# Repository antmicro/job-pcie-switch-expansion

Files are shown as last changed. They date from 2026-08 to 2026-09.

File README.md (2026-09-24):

# PCIe Switch Expansion for Antmicro Baseboard for NVIDIA Jetson Orin

Copyright (c) 2026 [Antmicro](https://www.antmicro.com)
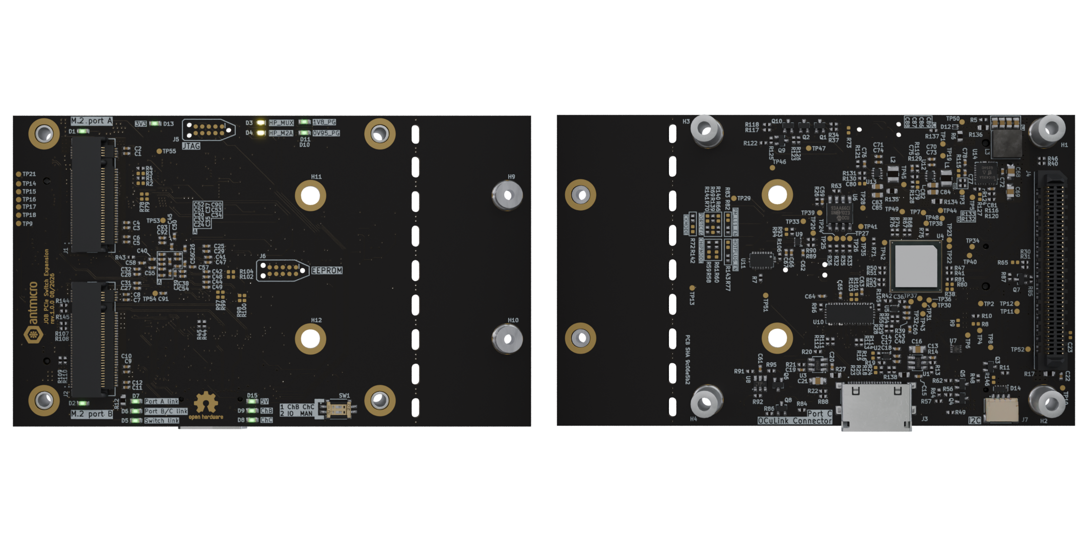
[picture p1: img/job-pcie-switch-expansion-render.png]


## Overview

This project contains open hardware PCB design files for an expansion board compatible with Antmicro's [Baseboard for Jetson Orin](https://github.com/antmicro/jetson-orin-baseboard).
The design includes a PCIe 3.0 switch that expands the number of available PCIe ports by connecting multiple PCIe endpoint devices to a single PCIe root complex.
The expansion board includes an OCuLink Connector and two M.2 (key-M) slots intended for connecting additional storage solutions with optional RAID support.
Both M.2 slots support 2280 and 2242 M.2 NVMe drives.
The design files were prepared in KiCad 10.x.

## Key features

* Accessory compatible with expansion connector located on Antmicro Baseboard NVIDIA Jetson Orin
* Supports for 2280 and 2242 M.2 NVMe drives
* 1x M.2 key M PCIe x2 slot 
* 1x M.2 key M or 1x OCuLink Connector PCIe x2 (multiplexed lane)
* 100 x 60 mm (3.94 x 2.36 inch) PCB outline

## Project structure 

The main directory contains KiCad PCB project files, the LICENSE, and this README, and the img directory contains graphics for this README.

## Licensing

This project is published under the [Apache-2.0](LICENSE) license.

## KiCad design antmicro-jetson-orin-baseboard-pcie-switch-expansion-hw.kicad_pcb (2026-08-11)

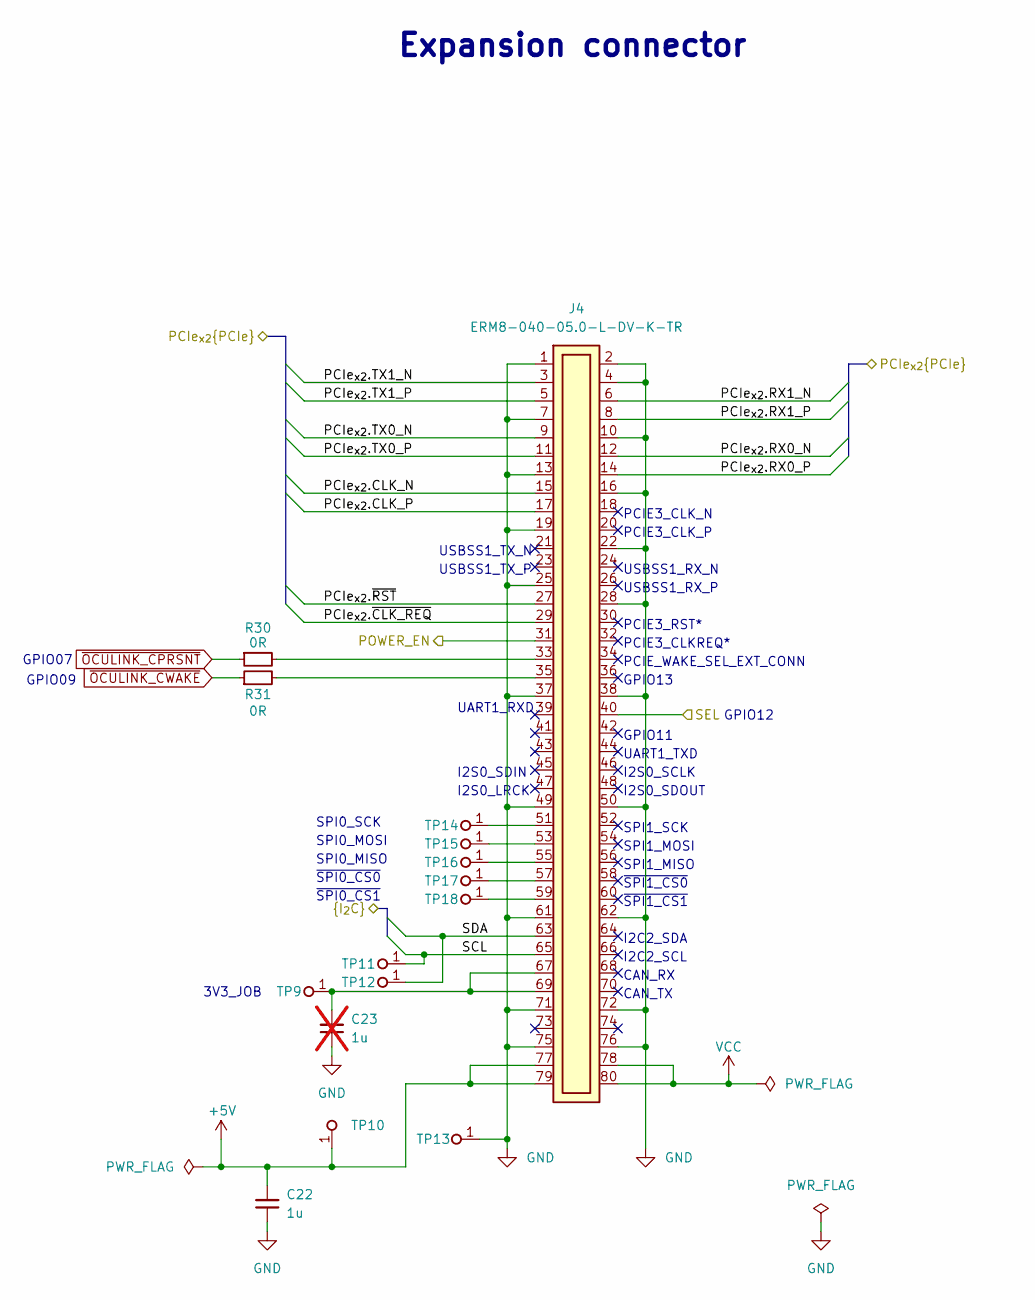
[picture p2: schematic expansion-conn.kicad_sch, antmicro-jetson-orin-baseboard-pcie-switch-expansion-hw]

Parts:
C22: C_1u_0402; C_0402_1005Metric; MPN C1005X6S1A105K050BC
C23: C_1u_0402; C_0402_1005Metric; MPN C1005X6S1A105K050BC; not fitted
J4: Plug_Samtec_ERM8_2x40_ERM8-040-05.0-L-DV-K-TR; Conn_Plug_Samtec_ERM8_2x40_ERM8-040-05.0-L-DV-K-TR; MPN ERM8-040-05.0-L-DV-K-TR
R30, R31: R_0R_0402; R_0402_1005Metric; MPN ERJ2GE0R00X
TP9, TP10, TP11, TP12, TP13, TP14, TP15, TP16, TP17, TP18: TP_0.75mm_SMD; TP_SMD_0.75mm

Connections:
+5V: C22.2, J4.77, J4.79, TP10.1 (1_1); also elsewhere on the board
/Expansion Connector/PCIe_{x2}.CLK_N: J4.15; also elsewhere on the board
/Expansion Connector/PCIe_{x2}.CLK_P: J4.17; also elsewhere on the board
/Expansion Connector/PCIe_{x2}.RX0_N: J4.12; also elsewhere on the board
/Expansion Connector/PCIe_{x2}.RX0_P: J4.14; also elsewhere on the board
/Expansion Connector/PCIe_{x2}.RX1_N: J4.6; also elsewhere on the board
/Expansion Connector/PCIe_{x2}.RX1_P: J4.8; also elsewhere on the board
/Expansion Connector/PCIe_{x2}.TX0_N: J4.9; also elsewhere on the board
/Expansion Connector/PCIe_{x2}.TX0_P: J4.11; also elsewhere on the board
/Expansion Connector/PCIe_{x2}.TX1_N: J4.3; also elsewhere on the board
/Expansion Connector/PCIe_{x2}.TX1_P: J4.5; also elsewhere on the board
/Expansion Connector/PCIe_{x2}.~CLK_REQ: J4.29; also elsewhere on the board
/Expansion Connector/PCIe_{x2}.~RST: J4.27; also elsewhere on the board
/Expansion Connector/POWER_EN: J4.31; also elsewhere on the board
/Expansion Connector/SCL: J4.65, TP11.1 (1_1); also elsewhere on the board
/Expansion Connector/SDA: J4.63, TP12.1 (1_1); also elsewhere on the board
/Expansion Connector/SEL: J4.40; also elsewhere on the board
GND: C22.1, C23.1, J4.1, J4.2, J4.4, J4.7, J4.10, J4.13, J4.16, J4.19, J4.22, J4.25, J4.28, J4.37, J4.38, J4.49, J4.50, J4.61, J4.62, J4.71, J4.72, J4.75, J4.76, TP13.1 (1_1); also elsewhere on the board
unnamed: C23.2, J4.67, J4.69, TP9.1 (1_1)
unnamed: J4.33, R30.2
unnamed: J4.35, R31.2
unnamed: J4.51, TP14.1 (1_1)
unnamed: J4.53, TP15.1 (1_1)
unnamed: J4.55, TP16.1 (1_1)
unnamed: J4.57, TP17.1 (1_1)
unnamed: J4.59, TP18.1 (1_1)
VCC: J4.78, J4.80; also elsewhere on the board
~OCULINK_CPRSNT: R30.1; also elsewhere on the board
~OCULINK_CWAKE: R31.1; also elsewhere on the board

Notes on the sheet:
USBSS1_RX_P
~{SPI1_CS1}
SPI0_MOSI
UART1_RXD
I2S0_SDOUT
PCIE3_CLK_N
~{SPI0_CS0}
I2S0_SDIN
USBSS1_RX_N
GPIO07
CAN_TX
PCIE3_CLK_P
SPI0_MISO
~{SPI0_CS1}
I2S0_LRCK
PCIE3_CLKREQ*
USBSS1_TX_P
I2C2_SCL
SPI1_MISO
SPI0_SCK
UART1_TXD
GPIO11
SPI1_MOSI
PCIE3_RST*
I2C2_SDA
~{SPI1_CS0}
GPIO13
CAN_RX
GPIO12
PCIE_WAKE_SEL_EXT_CONN
Expansion connector
USBSS1_TX_N
GPIO09
3V3_JOB
I2S0_SCLK
SPI1_SCK

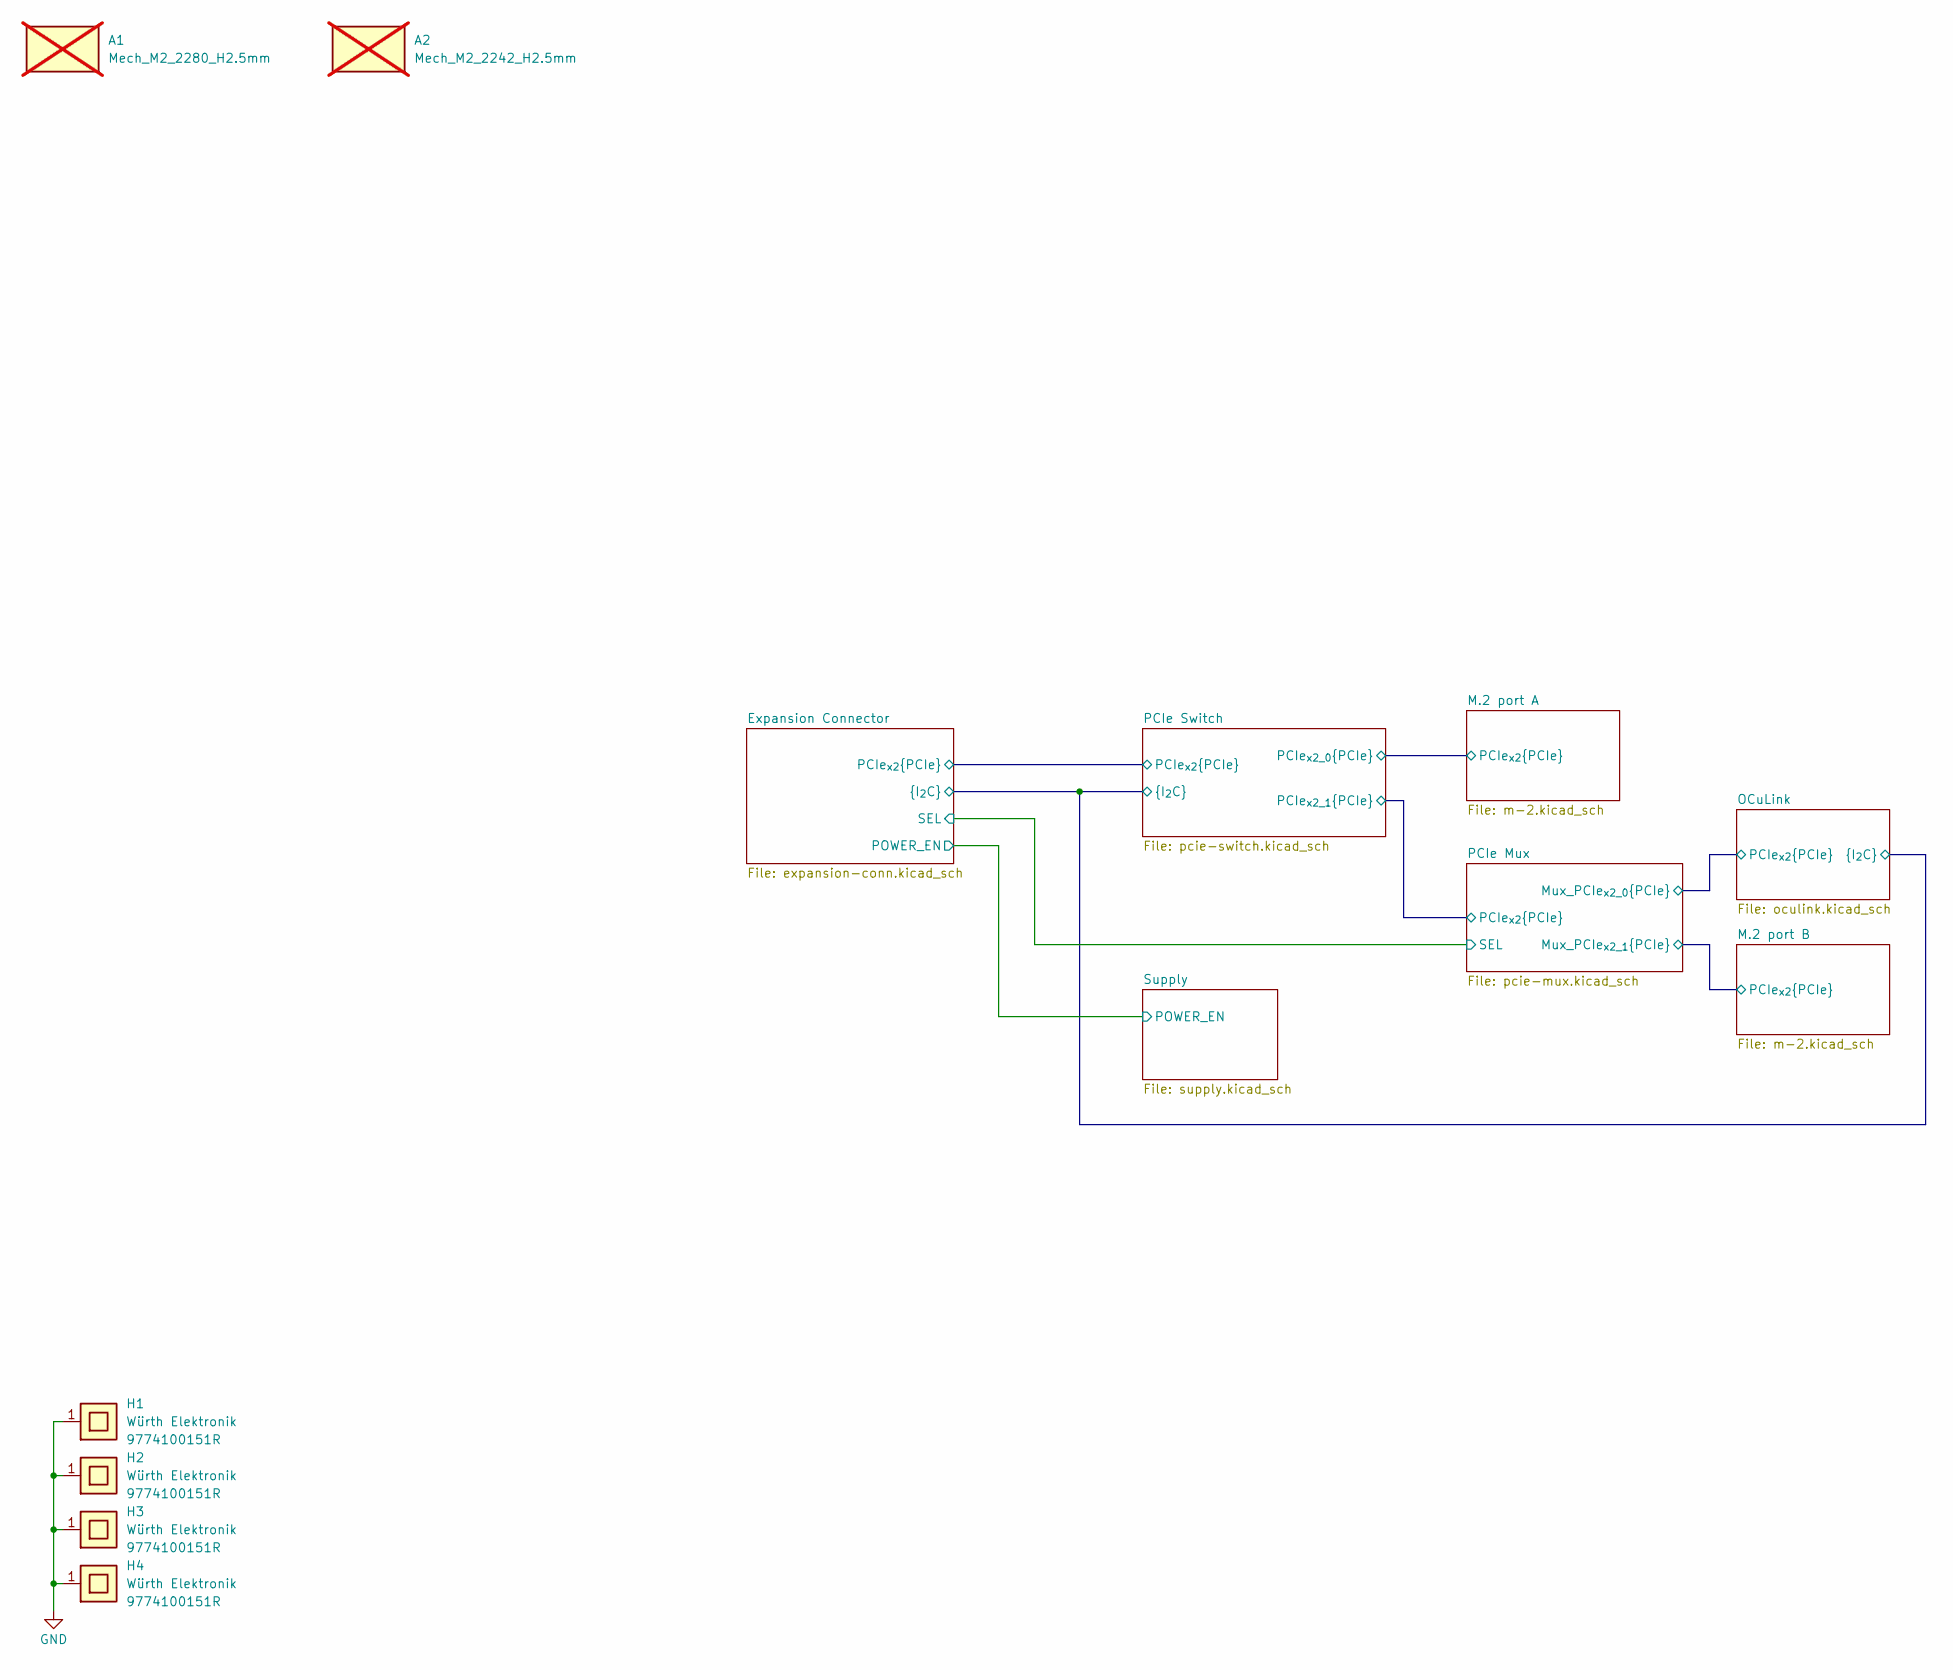
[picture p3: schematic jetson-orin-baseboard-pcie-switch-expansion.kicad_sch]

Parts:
A1: Mech_M2_2280_H2.5mm; not fitted
A2: Mech_M2_2242_H2.5mm; not fitted
H1, H2, H3, H4: Spacer_Drill3.7mm_H10mm_9774100151R; MPN 9774100151R

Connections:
GND: H1.1, H2.1, H3.1, H4.1; also elsewhere on the board

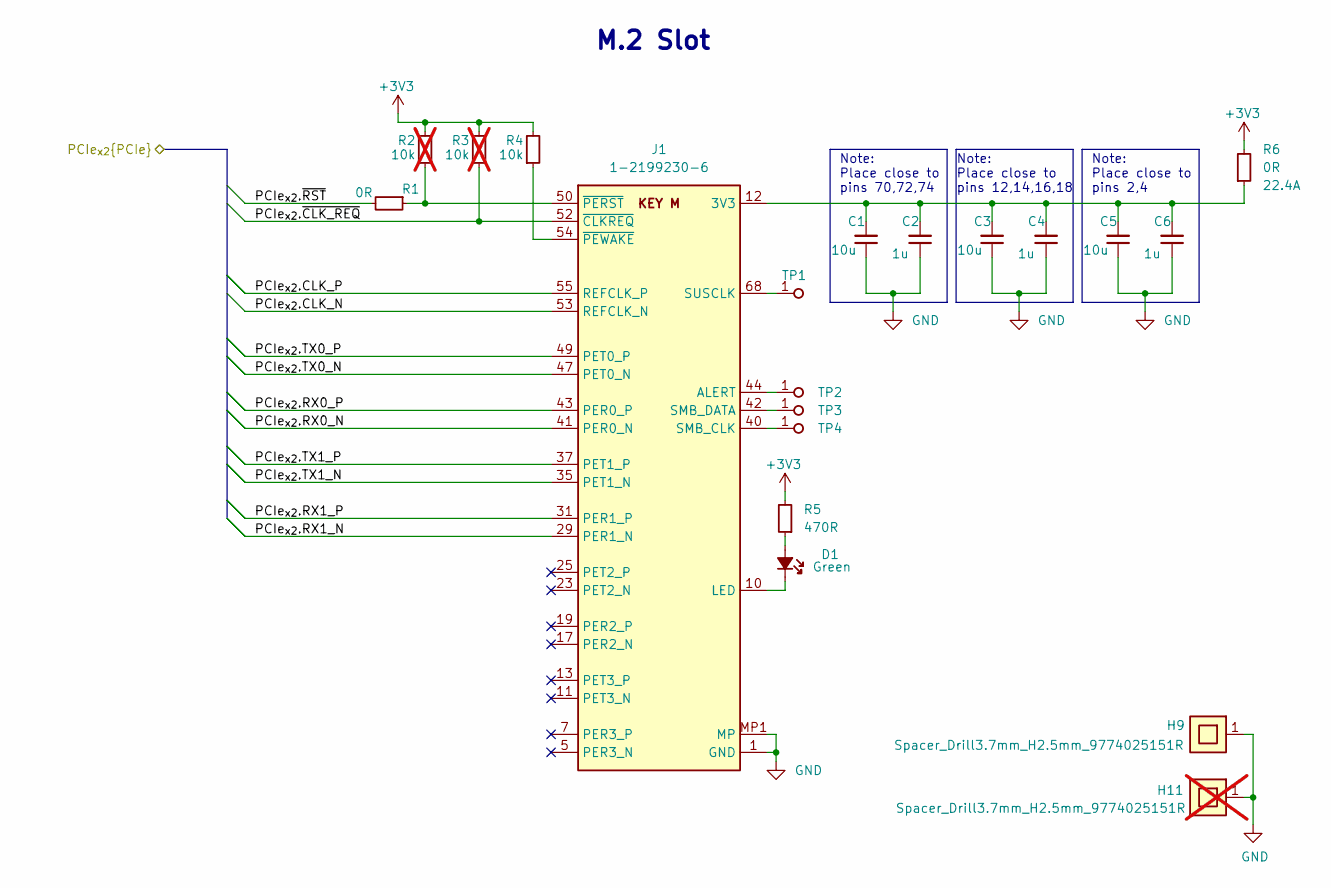
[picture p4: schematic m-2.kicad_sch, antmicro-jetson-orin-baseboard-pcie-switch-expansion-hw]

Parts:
C1, C3, C5: C_10u_0402; C_0402_1005Metric; MPN CC0402MRX5R5BB106
C2, C4, C6: C_1u_0402; C_0402_1005Metric; MPN C1005X6S1A105K050BC
D1: LED_G_0603_KP-1608CGCK; LED_0603_1608Metric_G; MPN KP-1608CGCK
H9: Spacer_Drill3.7mm_H2.5mm_9774025151R; MPN 9774025151R
H11: Spacer_Drill3.7mm_H2.5mm_9774025151R; MPN 9774025151R; not fitted
J1: Bus_M.2_1-2199230-6; Bus_M.2_Socket_Key_M_TE_1-2199230-6; MPN 1-2199230-6
R1: R_0R_0402; R_0402_1005Metric; MPN ERJ2GE0R00X
R2, R3: R_10k_0402; R_0402_1005Metric; Tolerance 1%; MPN CR0402-FX-1002GLF; not fitted
R4: R_10k_0402; R_0402_1005Metric; Tolerance 1%; MPN CR0402-FX-1002GLF
R5: R_470R_0402; R_0402_1005Metric; Tolerance 1%; MPN CR0402-FX-4700GLF
R6: R_0R_22.4A_0603; R_0603_1608Metric; Tolerance template_tolerance; MPN PMR03EZPJ000
TP1, TP2, TP3, TP4: TP_0.75mm_SMD; TP_SMD_0.75mm

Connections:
+3V3: R2.2, R3.2, R4.2, R5.2, R6.2; also elsewhere on the board
/M.2 port A/PCIe_{x2}.CLK_N: J1.53 (REFCLK_N); also elsewhere on the board
/M.2 port A/PCIe_{x2}.CLK_P: J1.55 (REFCLK_P); also elsewhere on the board
/M.2 port A/PCIe_{x2}.RX0_N: J1.41 (PER0_N); also elsewhere on the board
/M.2 port A/PCIe_{x2}.RX0_P: J1.43 (PER0_P); also elsewhere on the board
/M.2 port A/PCIe_{x2}.RX1_N: J1.29 (PER1_N); also elsewhere on the board
/M.2 port A/PCIe_{x2}.RX1_P: J1.31 (PER1_P); also elsewhere on the board
/M.2 port A/PCIe_{x2}.TX0_N: J1.47 (PET0_N); also elsewhere on the board
/M.2 port A/PCIe_{x2}.TX0_P: J1.49 (PET0_P); also elsewhere on the board
/M.2 port A/PCIe_{x2}.TX1_N: J1.35 (PET1_N); also elsewhere on the board
/M.2 port A/PCIe_{x2}.TX1_P: J1.37 (PET1_P); also elsewhere on the board
/M.2 port A/PCIe_{x2}.~CLK_REQ: J1.52 (~CLKREQ), R3.1; also elsewhere on the board
/M.2 port A/PCIe_{x2}.~RST: R1.2; also elsewhere on the board
GND: C1.1, C2.1, C3.1, C4.1, C5.1, C6.1, H9.1, H11.1, J1.1 (GND), J1.3 (GND), J1.9 (GND), J1.15 (GND), J1.21 (GND), J1.27 (GND), J1.33 (GND), J1.39 (GND), J1.45 (GND), J1.51 (GND), J1.57 (GND), J1.71 (GND), J1.73 (GND), J1.75 (GND), J1.MP1 (MP), J1.MP2 (MP); also elsewhere on the board
unnamed: C1.2, C2.2, C3.2, C4.2, C5.2, C6.2, J1.2 (3V3), J1.4 (3V3), J1.12 (3V3), J1.14 (3V3), J1.16 (3V3), J1.18 (3V3), J1.70 (3V3), J1.72 (3V3), J1.74 (3V3), R6.1
unnamed: D1.2 (A), R5.1
unnamed: D1.1 (C), J1.10 (LED)
unnamed: J1.44 (ALERT), TP2.1 (1_1)
unnamed: J1.40 (SMB_CLK), TP4.1 (1_1)
unnamed: J1.42 (SMB_DATA), TP3.1 (1_1)
unnamed: J1.68 (SUSCLK), TP1.1 (1_1)
unnamed: J1.50 (~PERST), R1.1, R2.1
unnamed: J1.54 (~PEWAKE), R4.1

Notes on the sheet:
Note: Place close to pins 2,4
M.2 Slot
Note: Place close to pins 12,14,16,18
Note: Place close to pins 70,72,74

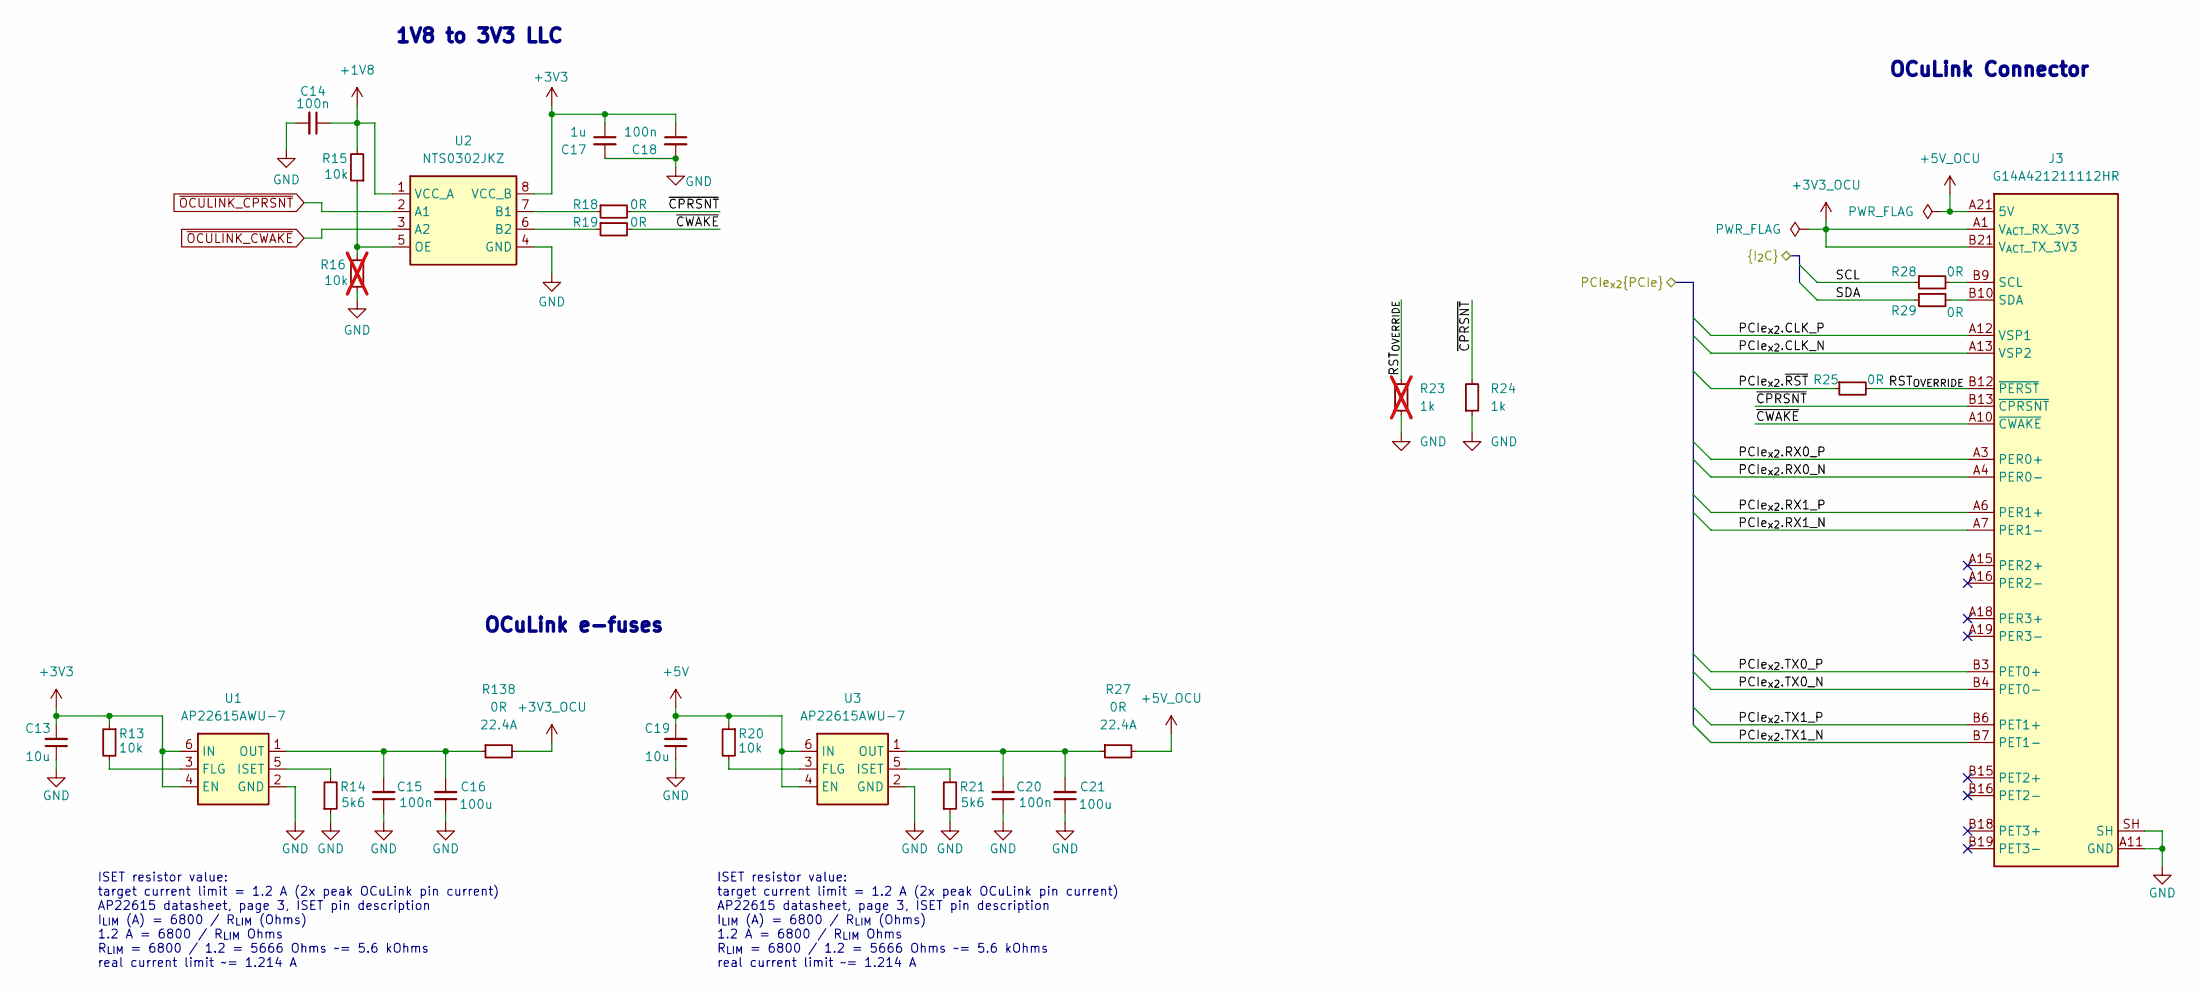
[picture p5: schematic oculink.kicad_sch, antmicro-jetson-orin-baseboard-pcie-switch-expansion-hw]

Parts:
C13, C19: C_10u_0402; C_0402_1005Metric; MPN CC0402MRX5R5BB106
C14, C15, C18, C20: C_100n_0402; C_0402_1005Metric; Voltage 50V; MPN GRM155R61H104KE14D
C16, C21: C_100u_0805; C_0805_2012Metric; MPN GRM21BR60J107ME15L
C17: C_1u_0402; C_0402_1005Metric; MPN C1005X6S1A105K050BC
J3: OCuLink_x4_Amphenol_G14A421211112HR; Amphenol_G14A421211112HR; MPN G14A421211112HR
R13, R15, R20: R_10k_0402; R_0402_1005Metric; Tolerance 1%; MPN CR0402-FX-1002GLF
R14, R21: R_5k6_0402; R_0402_1005Metric; Tolerance 1%; MPN CR0402-FX-5601GLF
R16: R_10k_0402; R_0402_1005Metric; Tolerance 1%; MPN CR0402-FX-1002GLF; not fitted
R18, R19, R25, R28, R29: R_0R_0402; R_0402_1005Metric; MPN ERJ2GE0R00X
R23: R_1k_0402; R_0402_1005Metric; Tolerance 1%; MPN CR0402-FX-1001GLF; not fitted
R24: R_1k_0402; R_0402_1005Metric; Tolerance 1%; MPN CR0402-FX-1001GLF
R27, R138: R_0R_22.4A_0603; R_0603_1608Metric; Tolerance template_tolerance; MPN PMR03EZPJ000
U1, U3: TSOT23-6; MPN AP22615AWU-7
U2: NTS0302JKZ; X2SON8_1.4x1x0.32mm_P0.35mm; MPN NTS0302JKZ

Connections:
+1V8: C14.1, R15.2, U2.1 (VCC_A); also elsewhere on the board
+3V3: C13.2, C17.1, C18.1, R13.1, U1.4 (EN), U1.6 (IN), U2.8 (VCC_B); also elsewhere on the board
+3V3_OCU: J3.A1 (V_{ACT}_RX_3V3), J3.B21 (V_{ACT}_TX_3V3), R138.2
+5V: C19.2, R20.1, U3.4 (EN), U3.6 (IN); also elsewhere on the board
+5V_OCU: J3.A21 (5V), J3.B1 (5V), R27.2
/Expansion Connector/SCL: R28.1; also elsewhere on the board
/Expansion Connector/SDA: R29.1; also elsewhere on the board
/OCuLink/PCIe_{x2}.CLK_N: J3.A13 (VSP2); also elsewhere on the board
/OCuLink/PCIe_{x2}.CLK_P: J3.A12 (VSP1); also elsewhere on the board
/OCuLink/PCIe_{x2}.RX0_N: J3.A4 (PER0-); also elsewhere on the board
/OCuLink/PCIe_{x2}.RX0_P: J3.A3 (PER0+); also elsewhere on the board
/OCuLink/PCIe_{x2}.RX1_N: J3.A7 (PER1-); also elsewhere on the board
/OCuLink/PCIe_{x2}.RX1_P: J3.A6 (PER1+); also elsewhere on the board
/OCuLink/PCIe_{x2}.TX0_N: J3.B4 (PET0-); also elsewhere on the board
/OCuLink/PCIe_{x2}.TX0_P: J3.B3 (PET0+); also elsewhere on the board
/OCuLink/PCIe_{x2}.TX1_N: J3.B7 (PET1-); also elsewhere on the board
/OCuLink/PCIe_{x2}.TX1_P: J3.B6 (PET1+); also elsewhere on the board
/OCuLink/PCIe_{x2}.~RST: R25.1; also elsewhere on the board
/OCuLink/RST_{OVERRIDE}: J3.B12 (~PERST), R23.2, R25.2
/OCuLink/~CPRSNT: J3.B13 (~CPRSNT), R18.2, R24.2
/OCuLink/~CWAKE: J3.A10 (~CWAKE), R19.2
GND: C13.1, C14.2, C15.1, C16.1, C17.2, C18.2, C19.1, C20.1, C21.1, J3.A2 (GND), J3.A5 (GND), J3.A8 (GND), J3.A11 (GND), J3.A14 (GND), J3.A17 (GND), J3.A20 (GND), J3.B2 (GND), J3.B5 (GND), J3.B8 (GND), J3.B11 (GND), J3.B14 (GND), J3.B17 (GND), J3.B20 (GND), J3.SH, R14.1, R16.1, R21.1, R23.1, R24.1, U1.2 (GND), U2.4 (GND), U3.2 (GND); also elsewhere on the board
unnamed: J3.B9 (SCL), R28.2
unnamed: J3.B10 (SDA), R29.2
unnamed: R13.2, U1.3 (FLG)
unnamed: R14.2, U1.5 (ISET)
unnamed: C15.2, C16.2, R138.1, U1.1 (OUT)
unnamed: R18.1, U2.7 (B1)
unnamed: R19.1, U2.6 (B2)
unnamed: R15.1, R16.2, U2.5 (OE)
unnamed: R20.2, U3.3 (FLG)
unnamed: R21.2, U3.5 (ISET)
unnamed: C20.2, C21.2, R27.1, U3.1 (OUT)
~OCULINK_CPRSNT: U2.2 (A1); also elsewhere on the board
~OCULINK_CWAKE: U2.3 (A2); also elsewhere on the board

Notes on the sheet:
ISET resistor value: target current limit = 1.2 A (2x peak OCuLink pin current) AP22615 datasheet, page 3, ISET pin description I_{LIM} (A) = 6800 / R_{LIM} (Ohms) 1.2 A = 6800 / R_{LIM} Ohms R_{LIM} = 6800 / 1.2 = 5666 Ohms ~= 5.6 kOhms real current limit ~= 1.214 A
OCuLink e-fuses
1V8 to 3V3 LLC
OCuLink Connector

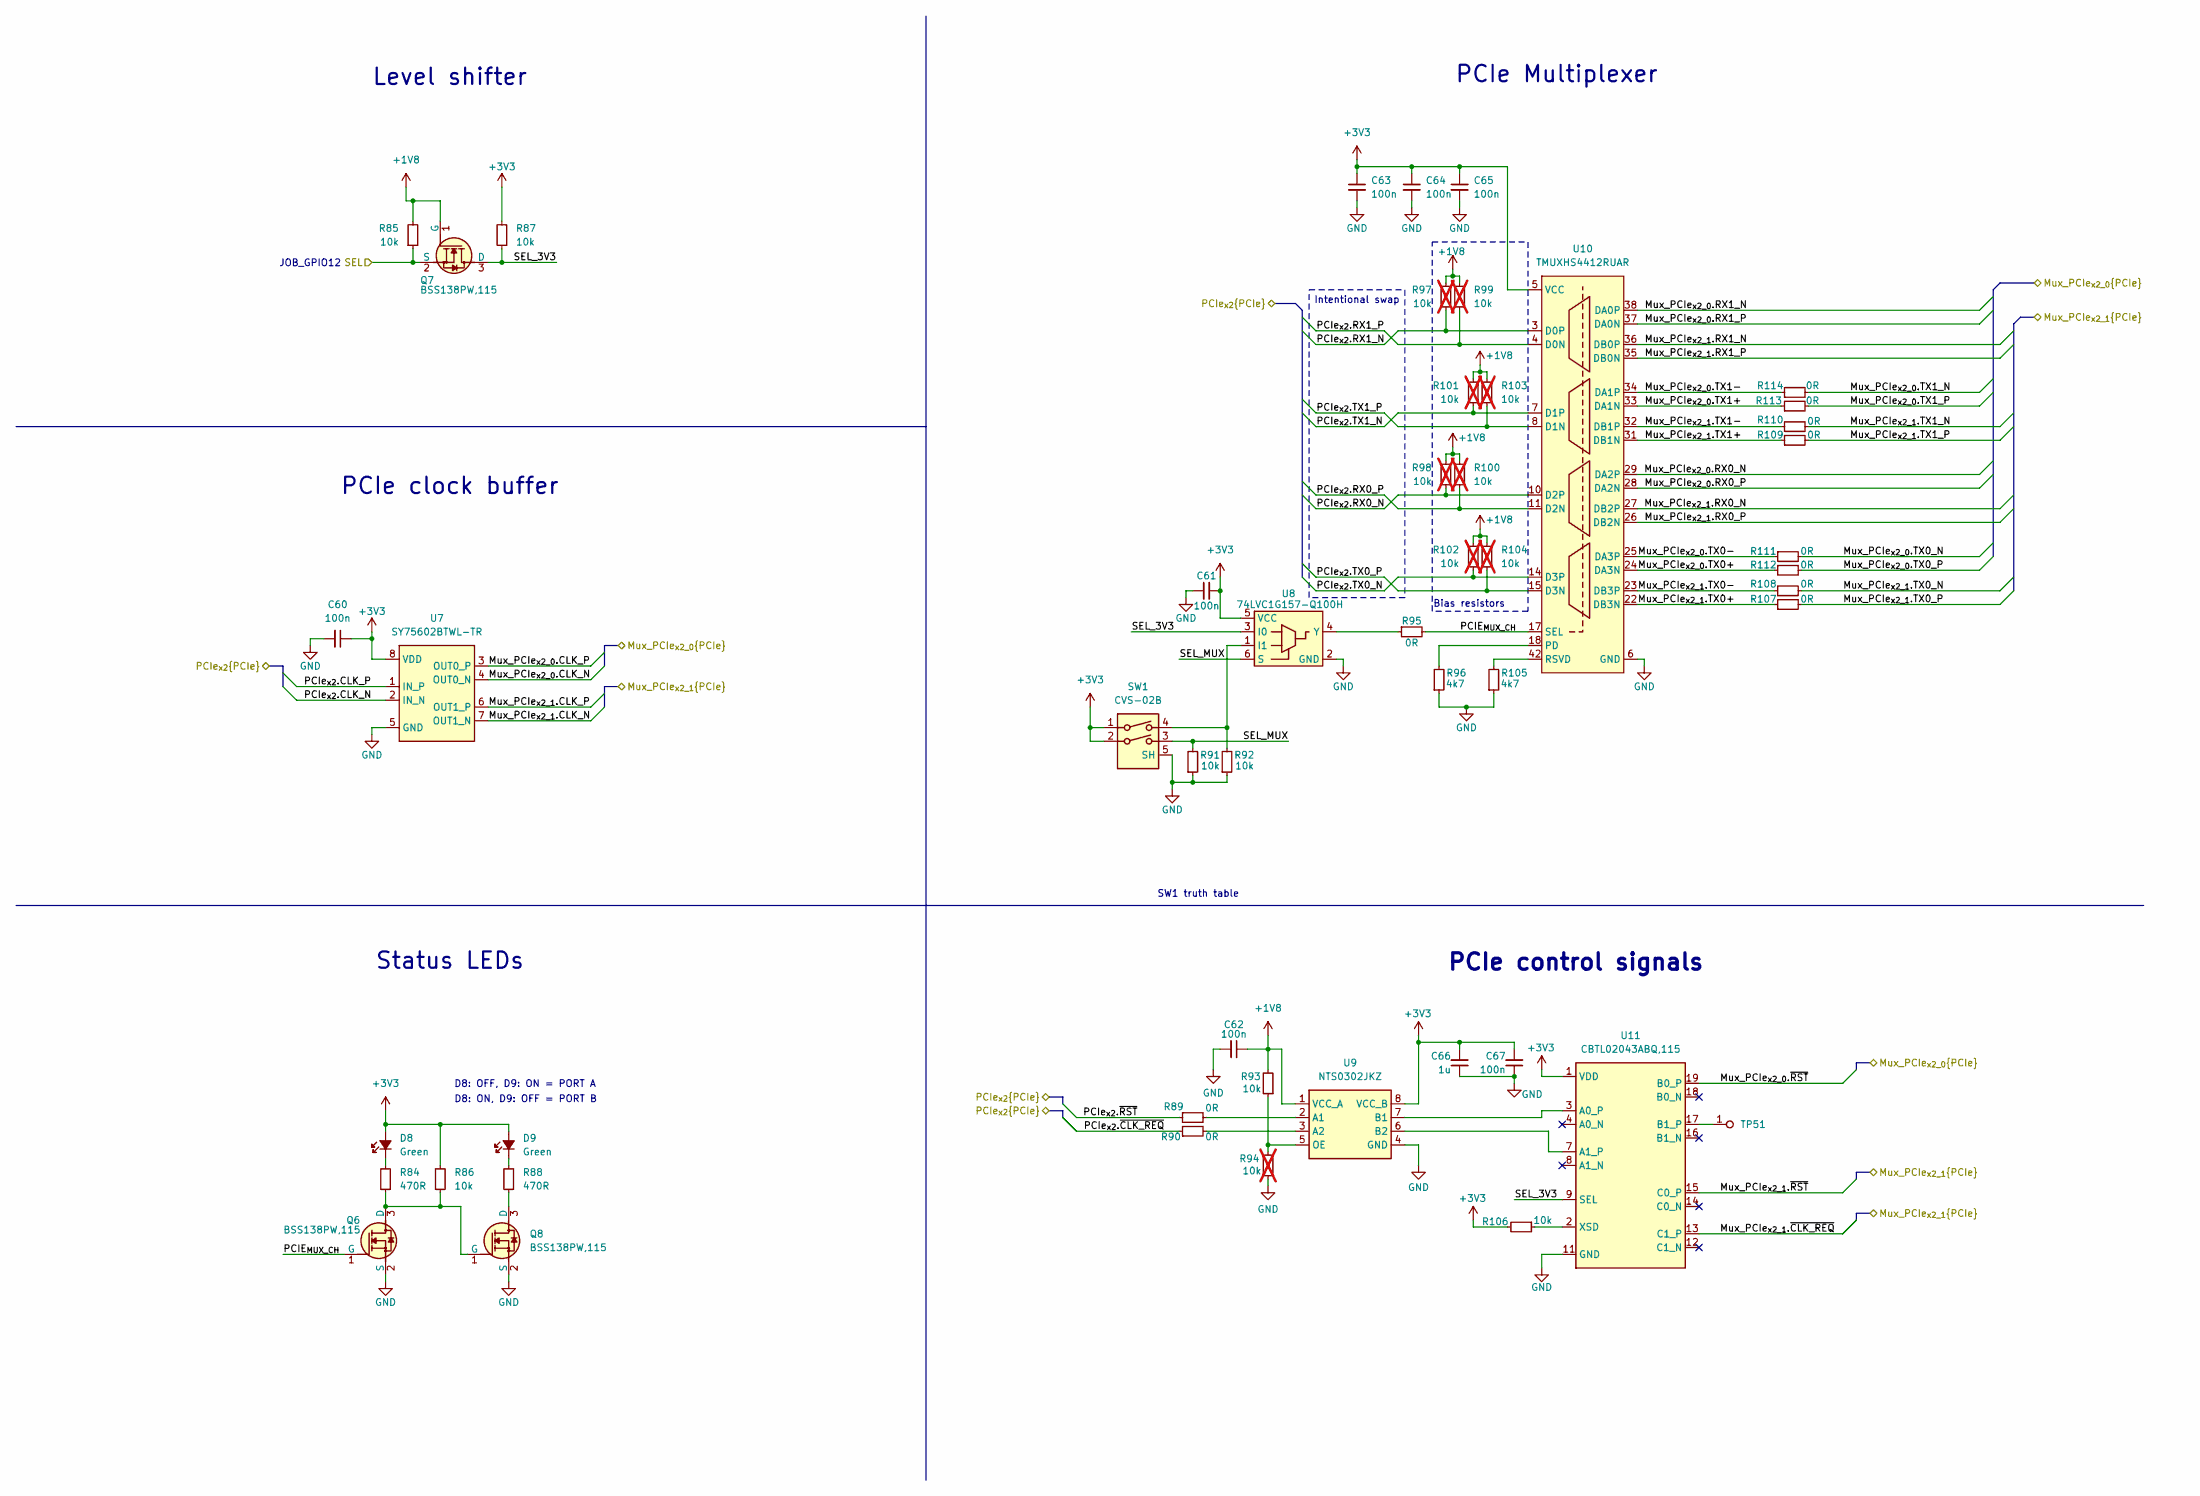
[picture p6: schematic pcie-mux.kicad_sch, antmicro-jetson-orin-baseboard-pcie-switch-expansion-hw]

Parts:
C60, C61, C62, C63, C64, C65, C67: C_100n_0402; C_0402_1005Metric; Voltage 50V; MPN GRM155R61H104KE14D
C66: C_1u_0402; C_0402_1005Metric; MPN C1005X6S1A105K050BC
D8, D9: LED_G_0603_LG_L29K-G2J1-24-Z; LED_0603_1608Metric_G; MPN LG L29K-G2J1-24-Z
Q6, Q7, Q8: BSS138PW,115; SC70-3; MPN BSS138PW,115
R84, R88: R_470R_0402; R_0402_1005Metric; Tolerance 1%; MPN CR0402-FX-4700GLF
R85, R86, R87, R91, R92, R93, R106: R_10k_0402; R_0402_1005Metric; Tolerance 1%; MPN CR0402-FX-1002GLF
R89, R90, R95, R107, R108, R109, R110, R111, R112, R113, R114: R_0R_0402; R_0402_1005Metric; MPN ERJ2GE0R00X
R94, R97, R98, R99, R100, R101, R102, R103, R104: R_10k_0402; R_0402_1005Metric; Tolerance 1%; MPN CR0402-FX-1002GLF; not fitted
R96, R105: R_4k7_0402; R_0402_1005Metric; Tolerance 1%; MPN CR0402-FX-4701GLF
SW1: SW_CVS-02B; SW_DIP_SPSTx02_Slide_Copal_CVS-02xB_W5.9mm_P1mm; MPN CVS-02B
TP51: TP_1mm_SMD; TP_SMD_1mm
U7: SY75602BTWL-TR; VDFN-8_1.6x1.4mm_P0.4mm; MPN SY75602BTWL-TR
U8: 74LVC1G157-Q100H_SOT457; SC-74-6_1.5x2.9mm_P0.95mm; MPN 74LVC1G157-Q100H
U9: NTS0302JKZ; X2SON8_1.4x1x0.32mm_P0.35mm; MPN NTS0302JKZ
U10: TMUXHS4412RUAR; WQFN-42-1EP_3.5x9mm_P0.5mm; MPN TMUXHS4412RUAR
U11: CBTL02043ABQ; DHVQFN-20-1EP_2.5x4.5_P0.5mm; MPN CBTL02043ABQ,115

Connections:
+1V8: C62.1, Q7.1 (G), R85.2, R93.2, R97.2, R98.2, R99.2, R100.2, R101.2, R102.2, R103.2, R104.2, U9.1 (VCC_A); also elsewhere on the board
+3V3: C60.1, C61.2, C63.1, C64.1, C65.1, C66.2, C67.2, D8.2 (A), D9.2 (A), R86.2, R87.2, R106.2, SW1.1, SW1.2, U7.8 (VDD), U8.5 (VCC), U9.8 (VCC_B), U10.5 (VCC), U10.13 (VCC), U11.1 (VDD), U11.6 (VDD), U11.10 (VDD); also elsewhere on the board
/Expansion Connector/SEL: Q7.2 (S), R85.1; also elsewhere on the board
/M.2 port B/PCIe_{x2}.CLK_N: U7.7 (OUT1_N); also elsewhere on the board
/M.2 port B/PCIe_{x2}.CLK_P: U7.6 (OUT1_P); also elsewhere on the board
/M.2 port B/PCIe_{x2}.RX0_N: U10.27 (DB2P); also elsewhere on the board
/M.2 port B/PCIe_{x2}.RX0_P: U10.26 (DB2N); also elsewhere on the board
/M.2 port B/PCIe_{x2}.RX1_N: U10.36 (DB0P); also elsewhere on the board
/M.2 port B/PCIe_{x2}.RX1_P: U10.35 (DB0N); also elsewhere on the board
/M.2 port B/PCIe_{x2}.TX0_N: R108.2; also elsewhere on the board
/M.2 port B/PCIe_{x2}.TX0_P: R107.2; also elsewhere on the board
/M.2 port B/PCIe_{x2}.TX1_N: R110.2; also elsewhere on the board
/M.2 port B/PCIe_{x2}.TX1_P: R109.2; also elsewhere on the board
/M.2 port B/PCIe_{x2}.~CLK_REQ: U11.13 (C1_P); also elsewhere on the board
/M.2 port B/PCIe_{x2}.~RST: U11.15 (C0_P); also elsewhere on the board
/OCuLink/PCIe_{x2}.CLK_N: U7.4 (OUT0_N); also elsewhere on the board
/OCuLink/PCIe_{x2}.CLK_P: U7.3 (OUT0_P); also elsewhere on the board
/OCuLink/PCIe_{x2}.RX0_N: U10.29 (DA2P); also elsewhere on the board
/OCuLink/PCIe_{x2}.RX0_P: U10.28 (DA2N); also elsewhere on the board
/OCuLink/PCIe_{x2}.RX1_N: U10.38 (DA0P); also elsewhere on the board
/OCuLink/PCIe_{x2}.RX1_P: U10.37 (DA0N); also elsewhere on the board
/OCuLink/PCIe_{x2}.TX0_N: R111.2; also elsewhere on the board
/OCuLink/PCIe_{x2}.TX0_P: R112.2; also elsewhere on the board
/OCuLink/PCIe_{x2}.TX1_N: R114.2; also elsewhere on the board
/OCuLink/PCIe_{x2}.TX1_P: R113.2; also elsewhere on the board
/OCuLink/PCIe_{x2}.~RST: U11.19 (B0_P); also elsewhere on the board
/PCIe Mux/Mux_PCIe_{x2_0}.TX0+: R112.1, U10.24 (DA3N)
/PCIe Mux/Mux_PCIe_{x2_0}.TX0-: R111.1, U10.25 (DA3P)
/PCIe Mux/Mux_PCIe_{x2_0}.TX1+: R113.1, U10.33 (DA1N)
/PCIe Mux/Mux_PCIe_{x2_0}.TX1-: R114.1, U10.34 (DA1P)
/PCIe Mux/Mux_PCIe_{x2_1}.TX0+: R107.1, U10.22 (DB3N)
/PCIe Mux/Mux_PCIe_{x2_1}.TX0-: R108.1, U10.23 (DB3P)
/PCIe Mux/Mux_PCIe_{x2_1}.TX1+: R109.1, U10.31 (DB1N)
/PCIe Mux/Mux_PCIe_{x2_1}.TX1-: R110.1, U10.32 (DB1P)
/PCIe Mux/PCIE_{MUX_CH}: Q6.1 (G), R95.2, U10.17 (SEL)
/PCIe Mux/PCIe_{x2}.CLK_N: U7.2 (IN_N); also elsewhere on the board
/PCIe Mux/PCIe_{x2}.CLK_P: U7.1 (IN_P); also elsewhere on the board
/PCIe Mux/PCIe_{x2}.RX0_N: R98.1, U10.10 (D2P); also elsewhere on the board
/PCIe Mux/PCIe_{x2}.RX0_P: R100.1, U10.11 (D2N); also elsewhere on the board
/PCIe Mux/PCIe_{x2}.RX1_N: R97.1, U10.3 (D0P); also elsewhere on the board
/PCIe Mux/PCIe_{x2}.RX1_P: R99.1, U10.4 (D0N); also elsewhere on the board
/PCIe Mux/PCIe_{x2}.TX0_N: R102.1, U10.14 (D3P); also elsewhere on the board
/PCIe Mux/PCIe_{x2}.TX0_P: R104.1, U10.15 (D3N); also elsewhere on the board
/PCIe Mux/PCIe_{x2}.TX1_N: R101.1, U10.7 (D1P); also elsewhere on the board
/PCIe Mux/PCIe_{x2}.TX1_P: R103.1, U10.8 (D1N); also elsewhere on the board
/PCIe Mux/PCIe_{x2}.~CLK_REQ: R90.1; also elsewhere on the board
/PCIe Mux/PCIe_{x2}.~RST: R89.1; also elsewhere on the board
/PCIe Mux/SEL_3V3: Q7.3 (D), R87.1, U8.3 (I0), U11.9 (SEL)
/PCIe Mux/SEL_MUX: R91.2, SW1.3, U8.6 (S)
GND: C60.2, C61.1, C62.2, C63.2, C64.2, C65.2, C66.1, C67.1, Q6.2 (S), Q8.2 (S), R91.1, R92.1, R94.1, R96.1, R105.1, SW1.5 (SH_5), U7.5 (GND), U8.2 (GND), U9.4 (GND), U10.6 (GND), U10.9 (GND), U10.16 (GND), U10.21 (GND), U10.30 (GND), U10.39 (GND), U10.43 (GND), U11.5 (GND), U11.11 (GND), U11.20 (GND), U11.21 (GND); also elsewhere on the board
unnamed: D8.1 (C), R84.2
unnamed: D9.1 (C), R88.2
unnamed: Q6.3 (D), Q8.1 (G), R84.1, R86.1
unnamed: Q8.3 (D), R88.1
unnamed: R92.2, SW1.4, U8.1 (I1)
unnamed: R95.1, U8.4 (Y)
unnamed: R89.2, U9.2 (A1)
unnamed: R90.2, U9.3 (A2)
unnamed: R93.1, R94.2, U9.5 (OE)
unnamed: R96.2, U10.18 (PD)
unnamed: R105.2, U10.42 (RSVD)
unnamed: U9.7 (B1), U11.3 (A0_P)
unnamed: U9.6 (B2), U11.7 (A1_P)
unnamed: TP51.1 (1_1), U11.17 (B1_P)
unnamed: R106.1, U11.2 (XSD)

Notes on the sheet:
JOB_GPIO12
Level shifter
PCIe clock buffer
SW1 truth table
PCIe Multiplexer
Bias resistors
Intentional swap
D8: OFF, D9: ON = PORT A
Status LEDs
D8: ON, D9: OFF = PORT B
PCIe control signals

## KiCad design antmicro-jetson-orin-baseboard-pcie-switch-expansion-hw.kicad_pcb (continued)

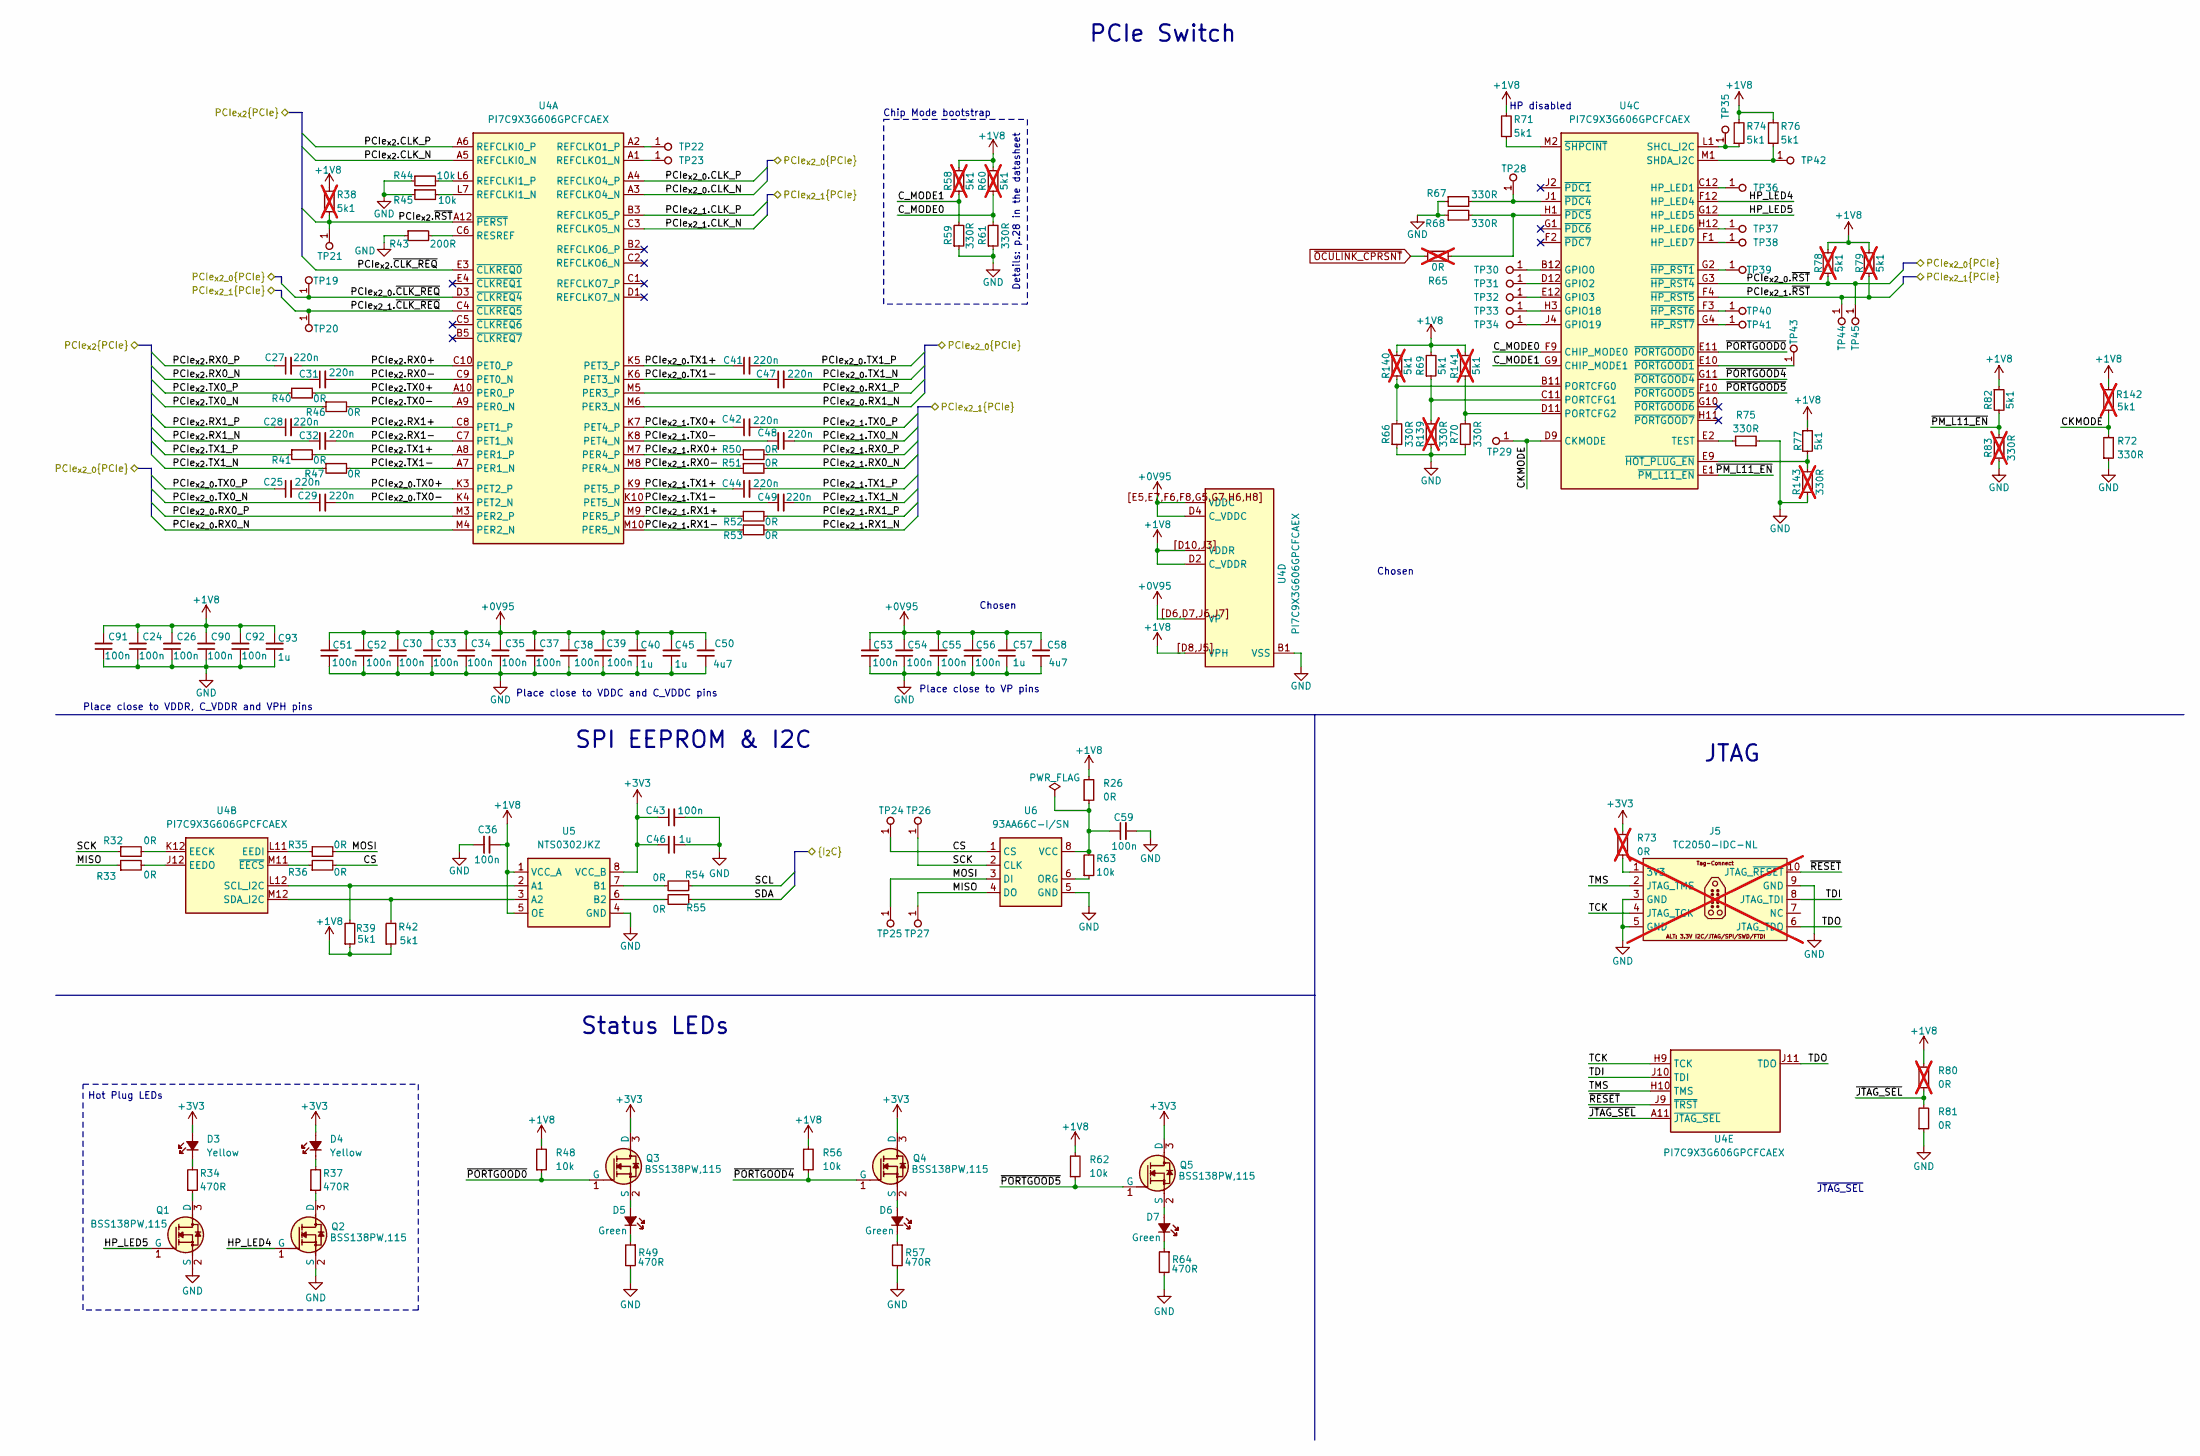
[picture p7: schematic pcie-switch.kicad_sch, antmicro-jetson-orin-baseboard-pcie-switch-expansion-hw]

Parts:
C24, C26, C30, C33, C34, C35, C36, C37, C38, C39, C43, C51, C52, C53, C54, C55, C56, C59, C90, C91, C92: C_100n_0402; C_0402_1005Metric; Voltage 50V; MPN GRM155R61H104KE14D
C25, C27, C28, C29, C31, C32, C41, C42, C44, C47, C48, C49: C_220n_0402; C_0402_1005Metric; MPN CC0402KRX5R6BB224
C40, C45, C46, C57, C93: C_1u_0402; C_0402_1005Metric; MPN C1005X6S1A105K050BC
C50, C58: C_4u7_25V_0402; C_0402_1005Metric; Voltage 25V; MPN GRM155C61E475ME15J
D3, D4: LED_Y_0402_VLMY1500-GS08; LED_0402_1005Metric_Y; MPN VLMY1500-GS08
D5, D6, D7: LED_G_0603_LG_L29K-G2J1-24-Z; LED_0603_1608Metric_G; MPN LG L29K-G2J1-24-Z
J5: Tag-Connect_TC2050-IDC-NL_2x5_P1.27mm; MPN TC2050-IDC-NL; not fitted
Q1, Q2, Q3, Q4, Q5: BSS138PW,115; SC70-3; MPN BSS138PW,115
R26, R32, R33, R35, R36, R40, R41, R46, R47, R50, R51, R52, R53, R54, R55, R81: R_0R_0402; R_0402_1005Metric; MPN ERJ2GE0R00X
R34, R37, R49, R57, R64: R_470R_0402; R_0402_1005Metric; Tolerance 1%; MPN CR0402-FX-4700GLF
R38, R58, R60, R78, R79, R140, R141, R142: R_5k1_0402; R_0402_1005Metric; Tolerance 1%; MPN CR0402-FX-5101GLF; not fitted
R39, R42, R69, R71, R74, R76, R77, R82: R_5k1_0402; R_0402_1005Metric; Tolerance 1%; MPN CR0402-FX-5101GLF
R43: R_200R_0402; R_0402_1005Metric; Tolerance 1%; MPN CR0402-FX-2000GLF
R44, R45, R48, R56, R62, R63: R_10k_0402; R_0402_1005Metric; Tolerance 1%; MPN CR0402-FX-1002GLF
R59, R61, R66, R67, R68, R70, R72, R75: R_330R_0402; R_0402_1005Metric; Tolerance 1%; MPN CR0402-FX-3300GLF
R65, R73, R80: R_0R_0402; R_0402_1005Metric; MPN ERJ2GE0R00X; not fitted
R83, R139, R143: R_330R_0402; R_0402_1005Metric; Tolerance 1%; MPN CR0402-FX-3300GLF; not fitted
TP19, TP20, TP21, TP22, TP23, TP28, TP29, TP30, TP31, TP32, TP33, TP34, TP35, TP36, TP37, TP38, TP39, TP40, TP41, TP42, TP43, TP44, TP45: TP_1mm_SMD; TP_SMD_1mm
TP24, TP25, TP26, TP27: TP_0.75mm_SMD; TP_SMD_0.75mm
U4: PI7C9X3G606GP; BGA-144_10x10mm_Layout12x12_P0.8mm; MPN PI7C9X3G606GPCFCAEX
U5: NTS0302JKZ; X2SON8_1.4x1x0.32mm_P0.35mm; MPN NTS0302JKZ
U6: 93AA66C_SOIC; SOIC-8_3.9x4.9x1.75mm_P1.27mm; MPN 93AA66C-I/SN

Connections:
+0V95: C30.2, C33.2, C34.2, C35.2, C37.2, C38.2, C39.2, C40.2, C45.2, C50.2, C51.2, C52.2, C53.2, C54.2, C55.2, C56.2, C57.2, C58.2, U4.D4 (C_VDDC), U4.D6 (VP), U4.D7 (VP), U4.E5 (VDDC), U4.E7 (VDDC), U4.F6 (VDDC), U4.F8 (VDDC), U4.G5 (VDDC), U4.G7 (VDDC), U4.H6 (VDDC), U4.H8 (VDDC), U4.J6 (VP), U4.J7 (VP), U4.[D6,D7,J6,J7] (VP), U4.[E5,E7,F6,F8,G5,G7,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 (VDDC); also elsewhere on the board
+1V8: C24.2, C26.2, C36.1, C90.2, C91.2, C92.2, C93.2, R26.2, R38.2, R39.1, R42.1, R48.2, R56.2, R58.2, R60.2, R62.2, R69.2, R71.2, R74.2, R76.2, R77.1, R78.1, R79.1, R80.2, R82.1, R140.2, R141.2, R142.1, U4.D2 (C_VDDR), U4.D8 (VPH), U4.D10 (VDDR), U4.J3 (VDDR), U4.J5 (VPH), U4.[D8,J5] (VPH), U4.[D10,J3] (VDDR), U5.1 (VCC_A), U5.5 (OE); also elsewhere on the board
+3V3: C43.1, C46.2, D3.2 (A), D4.2 (A), Q3.3 (D), Q4.3 (D), Q5.3 (D), R73.2, U5.8 (VCC_B); also elsewhere on the board
/Expansion Connector/PCIe_{x2}.CLK_N: U4.A5 (REFCLKI0_N); also elsewhere on the board
/Expansion Connector/PCIe_{x2}.CLK_P: U4.A6 (REFCLKI0_P); also elsewhere on the board
/Expansion Connector/PCIe_{x2}.RX0_N: C31.1; also elsewhere on the board
/Expansion Connector/PCIe_{x2}.RX0_P: C27.1; also elsewhere on the board
/Expansion Connector/PCIe_{x2}.RX1_N: C32.1; also elsewhere on the board
/Expansion Connector/PCIe_{x2}.RX1_P: C28.1; also elsewhere on the board
/Expansion Connector/PCIe_{x2}.TX0_N: R46.1; also elsewhere on the board
/Expansion Connector/PCIe_{x2}.TX0_P: R40.1; also elsewhere on the board
/Expansion Connector/PCIe_{x2}.TX1_N: R47.1; also elsewhere on the board
/Expansion Connector/PCIe_{x2}.TX1_P: R41.1; also elsewhere on the board
/Expansion Connector/PCIe_{x2}.~CLK_REQ: U4.E3 (~CLKREQ0); also elsewhere on the board
/Expansion Connector/PCIe_{x2}.~RST: R38.1, TP21.1 (1_1), U4.A12 (~PERST); also elsewhere on the board
/Expansion Connector/SCL: R54.1; also elsewhere on the board
/Expansion Connector/SDA: R55.1; also elsewhere on the board
/M.2 port A/PCIe_{x2}.CLK_N: U4.A3 (REFCLKO4_N); also elsewhere on the board
/M.2 port A/PCIe_{x2}.CLK_P: U4.A4 (REFCLKO4_P); also elsewhere on the board
/M.2 port A/PCIe_{x2}.RX0_N: U4.M4 (PER2_N); also elsewhere on the board
/M.2 port A/PCIe_{x2}.RX0_P: U4.M3 (PER2_P); also elsewhere on the board
/M.2 port A/PCIe_{x2}.RX1_N: U4.M6 (PER3_N); also elsewhere on the board
/M.2 port A/PCIe_{x2}.RX1_P: U4.M5 (PER3_P); also elsewhere on the board
/M.2 port A/PCIe_{x2}.TX0_N: C29.1; also elsewhere on the board
/M.2 port A/PCIe_{x2}.TX0_P: C25.1; also elsewhere on the board
/M.2 port A/PCIe_{x2}.TX1_N: C47.2; also elsewhere on the board
/M.2 port A/PCIe_{x2}.TX1_P: C41.2; also elsewhere on the board
/M.2 port A/PCIe_{x2}.~CLK_REQ: TP19.1 (1_1), U4.D3 (~CLKREQ4); also elsewhere on the board
/M.2 port A/PCIe_{x2}.~RST: R78.2, TP45.1 (1_1), U4.G3 (~HP_RST4); also elsewhere on the board
/PCIe Mux/PCIe_{x2}.CLK_N: U4.C3 (REFCLKO5_N); also elsewhere on the board
/PCIe Mux/PCIe_{x2}.CLK_P: U4.B3 (REFCLKO5_P); also elsewhere on the board
/PCIe Mux/PCIe_{x2}.RX0_N: R51.2; also elsewhere on the board
/PCIe Mux/PCIe_{x2}.RX0_P: R50.2; also elsewhere on the board
/PCIe Mux/PCIe_{x2}.RX1_N: R53.2; also elsewhere on the board
/PCIe Mux/PCIe_{x2}.RX1_P: R52.2; also elsewhere on the board
/PCIe Mux/PCIe_{x2}.TX0_N: C48.2; also elsewhere on the board
/PCIe Mux/PCIe_{x2}.TX0_P: C42.2; also elsewhere on the board
/PCIe Mux/PCIe_{x2}.TX1_N: C49.2; also elsewhere on the board
/PCIe Mux/PCIe_{x2}.TX1_P: C44.2; also elsewhere on the board
/PCIe Mux/PCIe_{x2}.~CLK_REQ: TP20.1 (1_1), U4.C4 (~CLKREQ5); also elsewhere on the board
/PCIe Mux/PCIe_{x2}.~RST: R79.2, TP44.1 (1_1), U4.F4 (~HP_RST5); also elsewhere on the board
/PCIe Switch/CKMODE: R72.2, R142.2, TP29.1 (1_1), U4.D9 (CKMODE)
/PCIe Switch/CS: R36.2, TP24.1 (1_1), U6.1 (CS)
/PCIe Switch/C_MODE0: R60.1, R61.2, U4.F9 (CHIP_MODE0)
/PCIe Switch/C_MODE1: R58.1, R59.2, U4.G9 (CHIP_MODE1)
/PCIe Switch/HP_LED4: Q2.1 (G), U4.F12 (HP_LED4)
/PCIe Switch/HP_LED5: Q1.1 (G), U4.G12 (HP_LED5)
/PCIe Switch/MISO: R33.1, TP27.1 (1_1), U6.4 (DO)
/PCIe Switch/MOSI: R35.2, TP25.1 (1_1), U6.3 (DI)
/PCIe Switch/PCIe_{x2_0}.TX0+: C25.2, U4.K3 (PET2_P)
/PCIe Switch/PCIe_{x2_0}.TX0-: C29.2, U4.K4 (PET2_N)
/PCIe Switch/PCIe_{x2_0}.TX1+: C41.1, U4.K5 (PET3_P)
/PCIe Switch/PCIe_{x2_0}.TX1-: C47.1, U4.K6 (PET3_N)
/PCIe Switch/PCIe_{x2_1}.RX0+: R50.1, U4.M7 (PER4_P)
/PCIe Switch/PCIe_{x2_1}.RX0-: R51.1, U4.M8 (PER4_N)
/PCIe Switch/PCIe_{x2_1}.RX1+: R52.1, U4.M9 (PER5_P)
/PCIe Switch/PCIe_{x2_1}.RX1-: R53.1, U4.M10 (PER5_N)
/PCIe Switch/PCIe_{x2_1}.TX0+: C42.1, U4.K7 (PET4_P)
/PCIe Switch/PCIe_{x2_1}.TX0-: C48.1, U4.K8 (PET4_N)
/PCIe Switch/PCIe_{x2_1}.TX1+: C44.1, U4.K9 (PET5_P)
/PCIe Switch/PCIe_{x2_1}.TX1-: C49.1, U4.K10 (PET5_N)
/PCIe Switch/PCIe_{x2}.RX0+: C27.2, U4.C10 (PET0_P)
/PCIe Switch/PCIe_{x2}.RX0-: C31.2, U4.C9 (PET0_N)
/PCIe Switch/PCIe_{x2}.RX1+: C28.2, U4.C8 (PET1_P)
/PCIe Switch/PCIe_{x2}.RX1-: C32.2, U4.C7 (PET1_N)
/PCIe Switch/PCIe_{x2}.TX0+: R40.2, U4.A10 (PER0_P)
/PCIe Switch/PCIe_{x2}.TX0-: R46.2, U4.A9 (PER0_N)
/PCIe Switch/PCIe_{x2}.TX1+: R41.2, U4.A8 (PER1_P)
/PCIe Switch/PCIe_{x2}.TX1-: R47.2, U4.A7 (PER1_N)
/PCIe Switch/SCK: R32.1, TP26.1 (1_1), U6.2 (CLK)
/PCIe Switch/TCK: J5.4 (JTAG_TCK), U4.H9 (TCK)
/PCIe Switch/TDI: J5.8 (JTAG_TDI), U4.J10 (TDI)
/PCIe Switch/TDO: J5.6 (JTAG_TDO), U4.J11 (TDO)
/PCIe Switch/TMS: J5.2 (JTAG_TMS), U4.H10 (TMS)
/PCIe Switch/~JTAG_SEL: R80.1, R81.2, U4.A11 (~JTAG_SEL)
/PCIe Switch/~PM_L11_EN: R82.2, R83.1, U4.E1 (~PM_L11_EN)
/PCIe Switch/~PORTGOOD0: Q3.1 (G), R48.1, U4.E11 (~PORTGOOD0)
/PCIe Switch/~PORTGOOD4: Q4.1 (G), R56.1, U4.G11 (~PORTGOOD4)
/PCIe Switch/~PORTGOOD5: Q5.1 (G), R62.1, U4.F10 (~PORTGOOD5)
/PCIe Switch/~RESET: J5.10 (JTAG_~RESET), U4.J9 (~TRST)
GND: C24.1, C26.1, C30.1, C33.1, C34.1, C35.1, C36.2, C37.1, C38.1, C39.1, C40.1, C43.2, C45.1, C46.1, C50.1, C51.1, C52.1, C53.1, C54.1, C55.1, C56.1, C57.1, C58.1, C59.2, C90.1, C91.1, C92.1, C93.1, J5.3 (GND), J5.5 (GND), J5.9 (GND), Q1.2 (S), Q2.2 (S), R43.1, R44.1, R45.1, R49.2, R57.2, R59.1, R61.1, R64.2, R66.1, R67.1, R68.1, R70.1, R72.1, R75.1, R81.1, R83.2, R139.1, R143.1, U4.B1 (VSS), U4.B4 (VSS), U4.B6 (VSS), U4.B7 (VSS), U4.B8 (VSS), U4.B9 (VSS), U4.B10 (VSS), U4.D5 (VSS), U4.E6 (VSS), U4.E8 (VSS), U4.F5 (VSS), U4.F7 (VSS), U4.F11 (VSS), U4.G6 (VSS), U4.G8 (VSS), U4.H5 (VSS), U4.H7 (VSS), U4.J8 (VSS), U4.K2 (VSS), U4.K11 (VSS), U4.L3 (VSS), U4.L4 (VSS), U4.L5 (VSS), U4.L8 (VSS), U4.L9 (VSS), U4.L10 (VSS), U5.4 (GND), U6.5 (GND); also elsewhere on the board
unnamed: D3.1 (C), R34.2
unnamed: D4.1 (C), R37.2
unnamed: D5.2 (A), Q3.2 (S)
unnamed: D5.1 (C), R49.1
unnamed: D6.2 (A), Q4.2 (S)
unnamed: D6.1 (C), R57.1
unnamed: D7.2 (A), Q5.2 (S)
unnamed: D7.1 (C), R64.1
unnamed: J5.1 (3V3), R73.1
unnamed: Q1.3 (D), R34.1
unnamed: Q2.3 (D), R37.1
unnamed: R45.2, U4.L7 (REFCLKI1_N)
unnamed: R44.2, U4.L6 (REFCLKI1_P)
unnamed: TP23.1 (1_1), U4.A1 (REFCLKO1_N)
unnamed: TP22.1 (1_1), U4.A2 (REFCLKO1_P)
unnamed: R43.2, U4.C6 (RESREF)
unnamed: R32.2, U4.K12 (EECK)
unnamed: R35.1, U4.L11 (EEDI)
unnamed: R33.2, U4.J12 (EEDO)
unnamed: R39.2, U4.L12 (SCL_I2C), U5.2 (A1)
unnamed: R42.2, U4.M12 (SDA_I2C), U5.3 (A2)
unnamed: R36.1, U4.M11 (~EECS)
unnamed: TP30.1 (1_1), U4.B12 (GPIO0)
unnamed: TP31.1 (1_1), U4.D12 (GPIO2)
unnamed: TP32.1 (1_1), U4.E12 (GPIO3)
unnamed: TP33.1 (1_1), U4.H3 (GPIO18)
unnamed: TP34.1 (1_1), U4.J4 (GPIO19)
unnamed: TP36.1 (1_1), U4.C12 (HP_LED1)
unnamed: TP37.1 (1_1), U4.H12 (HP_LED6)
unnamed: TP38.1 (1_1), U4.F1 (HP_LED7)
unnamed: R66.2, R140.1, U4.B11 (PORTCFG0)
unnamed: R69.1, R139.2, U4.C11 (PORTCFG1)
unnamed: R70.2, R141.1, U4.D11 (PORTCFG2)
unnamed: R74.1, TP35.1 (1_1), U4.L1 (SHCL_I2C)
unnamed: R76.1, TP42.1 (1_1), U4.M1 (SHDA_I2C)
unnamed: R75.2, U4.E2 (TEST)
unnamed: R77.2, R143.2, U4.E9 (~HOT_PLUG_EN)
unnamed: TP39.1 (1_1), U4.G2 (~HP_RST1)
unnamed: TP40.1 (1_1), U4.F3 (~HP_RST6)
unnamed: TP41.1 (1_1), U4.G4 (~HP_RST7)
unnamed: R67.2, TP28.1 (1_1), U4.J1 (~PDC4)
unnamed: R65.2, R68.2, U4.H1 (~PDC5)
unnamed: TP43.1 (1_1), U4.E10 (~PORTGOOD1)
unnamed: R71.1, U4.M2 (~SHPCINT)
unnamed: R54.2, U5.7 (B1)
unnamed: R55.2, U5.6 (B2)
unnamed: R63.1, U6.6 (ORG)
unnamed: C59.1, R26.1, R63.2, U6.8 (VCC)
~OCULINK_CPRSNT: R65.1; also elsewhere on the board

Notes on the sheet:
PCIe Switch
~{JTAG_SEL}
Hot Plug LEDs
Place close to VDDR, C_VDDR and VPH pins
Place close to VP pins
HP disabled
JTAG
Details: p.28 in the datasheet
Place close to VDDC and C_VDDC pins
Chosen
Status LEDs
SPI EEPROM & I2C
Chip Mode bootstrap

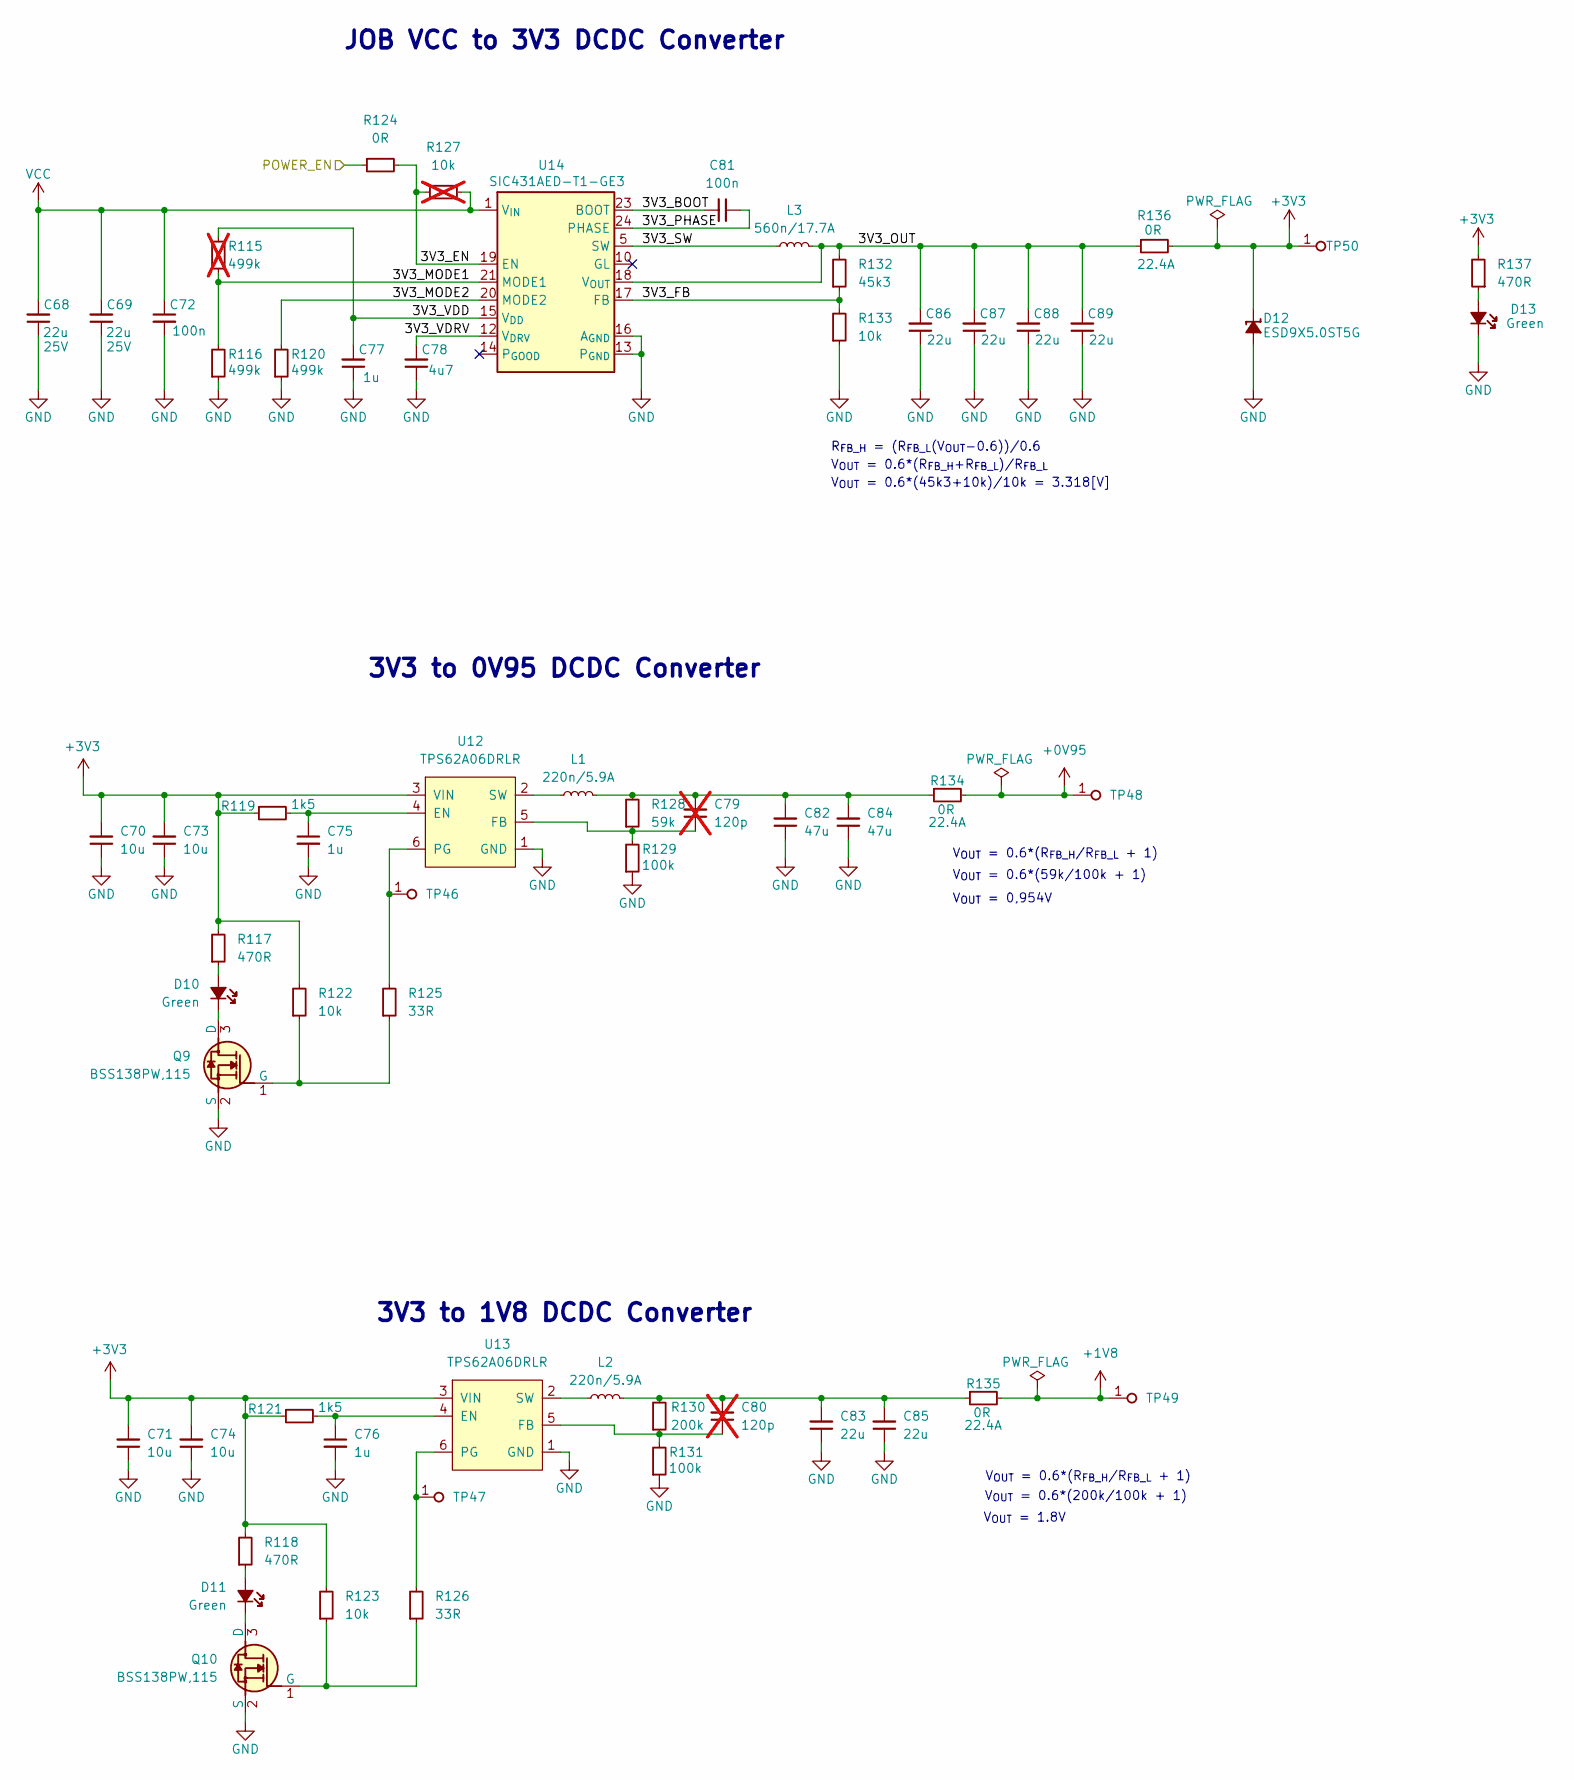
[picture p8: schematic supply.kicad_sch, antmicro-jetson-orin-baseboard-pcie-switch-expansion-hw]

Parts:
C68, C69: C_22u_25V_0805; C_0805_2012Metric; Voltage 25V; MPN CL21A226MAYNNNE
C70, C71, C73, C74: C_10u_0402; C_0402_1005Metric; MPN CC0402MRX5R5BB106
C72, C81: C_100n_0402; C_0402_1005Metric; Voltage 50V; MPN GRM155R61H104KE14D
C75, C76, C77: C_1u_0402; C_0402_1005Metric; MPN C1005X6S1A105K050BC
C78: C_4u7_25V_0402; C_0402_1005Metric; Voltage 25V; MPN GRM155C61E475ME15J
C79, C80: C_120p_100V_0402; C_0402_1005Metric; Voltage 100V; MPN C0402C121J5GACTU; not fitted
C82, C84: C_47u_0603; C_0603_1608Metric; MPN GRM188R60J476ME15D
C83, C85: C_22u_0603; C_0603_1608Metric; MPN GRM188R60J226MEA0D
C86, C87, C88, C89: C_22u_16V_0603; C_0603_1608Metric_EIA; Voltage 16V; MPN CL10A226MO7JZNC
D10, D11: LED_G_0603_LG_L29K-G2J1-24-Z; LED_0603_1608Metric_G; MPN LG L29K-G2J1-24-Z
D12: ESD9X5.0ST5G; SOD-923; MPN ESD9X5.0ST5G
D13: LED_G_0603_KP-1608CGCK; LED_0603_1608Metric_G; MPN KP-1608CGCK
L1, L2: L_220n_5.9A_1008; L_1008_2520Metric; MPN SRP2510TMA-R22M
L3: L_560n_17.7A_Bourns-SRP5030CA; L_Bourns-SRP5030CA; MPN SRP5030CA-R56M
Q9, Q10: BSS138PW,115; SC70-3; MPN BSS138PW,115
R115: R_499k_0402; R_0402_1005Metric; Tolerance 1%; MPN CR0402-FX-4993GLF; not fitted
R116, R120: R_499k_0402; R_0402_1005Metric; Tolerance 1%; MPN CR0402-FX-4993GLF
R117, R118, R137: R_470R_0402; R_0402_1005Metric; Tolerance 1%; MPN CR0402-FX-4700GLF
R119, R121: R_1k5_0402; R_0402_1005Metric; Tolerance 1%; MPN CR0402-FX-1501GLF
R122, R123, R133: R_10k_0402; R_0402_1005Metric; Tolerance 1%; MPN CR0402-FX-1002GLF
R124: R_0R_0402; R_0402_1005Metric; MPN ERJ2GE0R00X
R125, R126: R_33R_0402; R_0402_1005Metric; Tolerance 1%; MPN CR0402-FX-33R0GLF
R127: R_10k_0402; R_0402_1005Metric; Tolerance 1%; MPN CR0402-FX-1002GLF; not fitted
R128: R_59k_0402; R_0402_1005Metric; Tolerance 1%; MPN CR0402-FX-5902GLF
R129, R131: R_100k_0.1%_0402; R_0402_1005Metric; Tolerance 1%; MPN CR0402-FX-1003GLF
R130: R_200k_0402; R_0402_1005Metric; Tolerance 1%; MPN CR0402-FX-2003GLF
R132: R_45k3_0402; R_0402_1005Metric; Tolerance 1%; MPN CR0402-FX-4532GLF
R134, R135, R136: R_0R_22.4A_0603; R_0603_1608Metric; Tolerance template_tolerance; MPN PMR03EZPJ000
TP46, TP47, TP48, TP49, TP50: TP_0.75mm_SMD; TP_SMD_0.75mm
U12, U13: TPS62A06DRLR; SOT-563; MPN TPS62A06DRLR
U14: SIC431AED-T1-GE3; MLP44-24L_4x4x0.75mm; MPN SIC431AED-T1-GE3

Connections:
+0V95: R134.2, TP48.1 (1_1); also elsewhere on the board
+1V8: R135.2, TP49.1 (1_1); also elsewhere on the board
+3V3: C70.2, C71.2, C73.2, C74.2, D12.1 (C), R117.2, R118.2, R119.1, R121.1, R122.2, R123.2, R136.2, R137.2, TP50.1 (1_1), U12.3 (VIN), U13.3 (VIN); also elsewhere on the board
/Expansion Connector/POWER_EN: R124.1; also elsewhere on the board
/Supply/3V3_BOOT: C81.2, U14.23 (BOOT)
/Supply/3V3_EN: R124.2, R127.2, U14.19 (EN)
/Supply/3V3_FB: R132.1, R133.2, U14.17 (FB)
/Supply/3V3_MODE1: R115.1, R116.2, U14.21 (MODE1)
/Supply/3V3_MODE2: R120.2, U14.20 (MODE2)
/Supply/3V3_OUT: C86.2, C87.2, C88.2, C89.2, L3.2, R132.2, R136.1, U14.18 (V_{OUT})
/Supply/3V3_PHASE: C81.1, U14.24 (PHASE)
/Supply/3V3_SW: L3.1, U14.5 (SW), U14.6 (SW), U14.7 (SW), U14.8 (SW), U14.9 (SW)
/Supply/3V3_VDD: C77.2, R115.2, U14.15 (V_{DD})
/Supply/3V3_VDRV: C78.2, U14.12 (V_{DRV})
GND: C68.1, C69.1, C70.1, C71.1, C72.2, C73.1, C74.1, C75.2, C76.2, C77.1, C78.1, C82.1, C83.1, C84.1, C85.1, C86.1, C87.1, C88.1, C89.1, D12.2 (A), D13.1 (C), Q9.2 (S), Q10.2 (S), R116.1, R120.1, R129.1, R131.1, R133.1, U12.1 (GND), U13.1 (GND), U14.3 (P_{GND}), U14.4 (P_{GND}), U14.13 (P_{GND}), U14.16 (A_{GND}), U14.25 (A_{GND}), U14.27 (P_{GND}); also elsewhere on the board
unnamed: C79.2, C82.2, C84.2, L1.2, R128.2, R134.1
unnamed: C80.2, C83.2, C85.2, L2.2, R130.2, R135.1
unnamed: D10.2 (A), R117.1
unnamed: D10.1 (C), Q9.3 (D)
unnamed: D11.2 (A), R118.1
unnamed: D11.1 (C), Q10.3 (D)
unnamed: D13.2 (A), R137.1
unnamed: Q9.1 (G), R122.1, R125.1
unnamed: Q10.1 (G), R123.1, R126.1
unnamed: C75.1, R119.2, U12.4 (EN)
unnamed: C79.1, R128.1, R129.2, U12.5 (FB)
unnamed: R125.2, TP46.1 (1_1), U12.6 (PG)
unnamed: L1.1, U12.2 (SW)
unnamed: C76.1, R121.2, U13.4 (EN)
unnamed: C80.1, R130.1, R131.2, U13.5 (FB)
unnamed: R126.2, TP47.1 (1_1), U13.6 (PG)
unnamed: L2.1, U13.2 (SW)
VCC: C68.2, C69.2, C72.1, R127.1, U14.1 (V_{IN}), U14.2 (V_{IN}), U14.22 (V_{IN}), U14.26 (V_{IN}); also elsewhere on the board

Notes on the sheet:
3V3 to 1V8 DCDC Converter
V_{OUT} = 0.6*(R_{FB_H}+R_{FB_L})/R_{FB_L}
R_{FB_H} = (R_{FB_L}(V_{OUT}-0.6))/0.6
V_{OUT} = 0.6*(45k3+10k)/10k = 3.318[V]
V_{OUT} = 0.6*(R_{FB_H}/R_{FB_L} + 1)
V_{OUT} = 0.6*(59k/100k + 1)
3V3 to 0V95 DCDC Converter
JOB VCC to 3V3 DCDC Converter
V_{OUT} = 0,954V
V_{OUT} = 1.8V
V_{OUT} = 0.6*(200k/100k + 1)

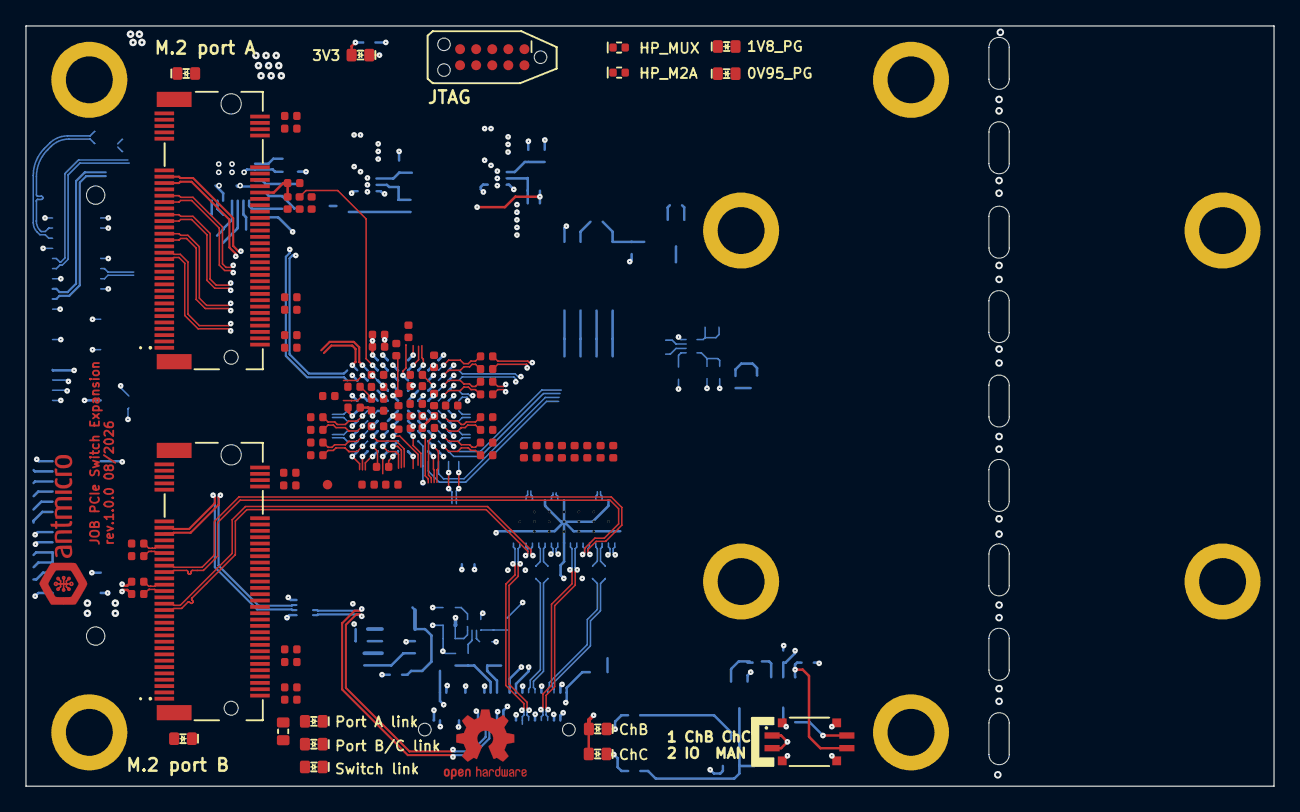
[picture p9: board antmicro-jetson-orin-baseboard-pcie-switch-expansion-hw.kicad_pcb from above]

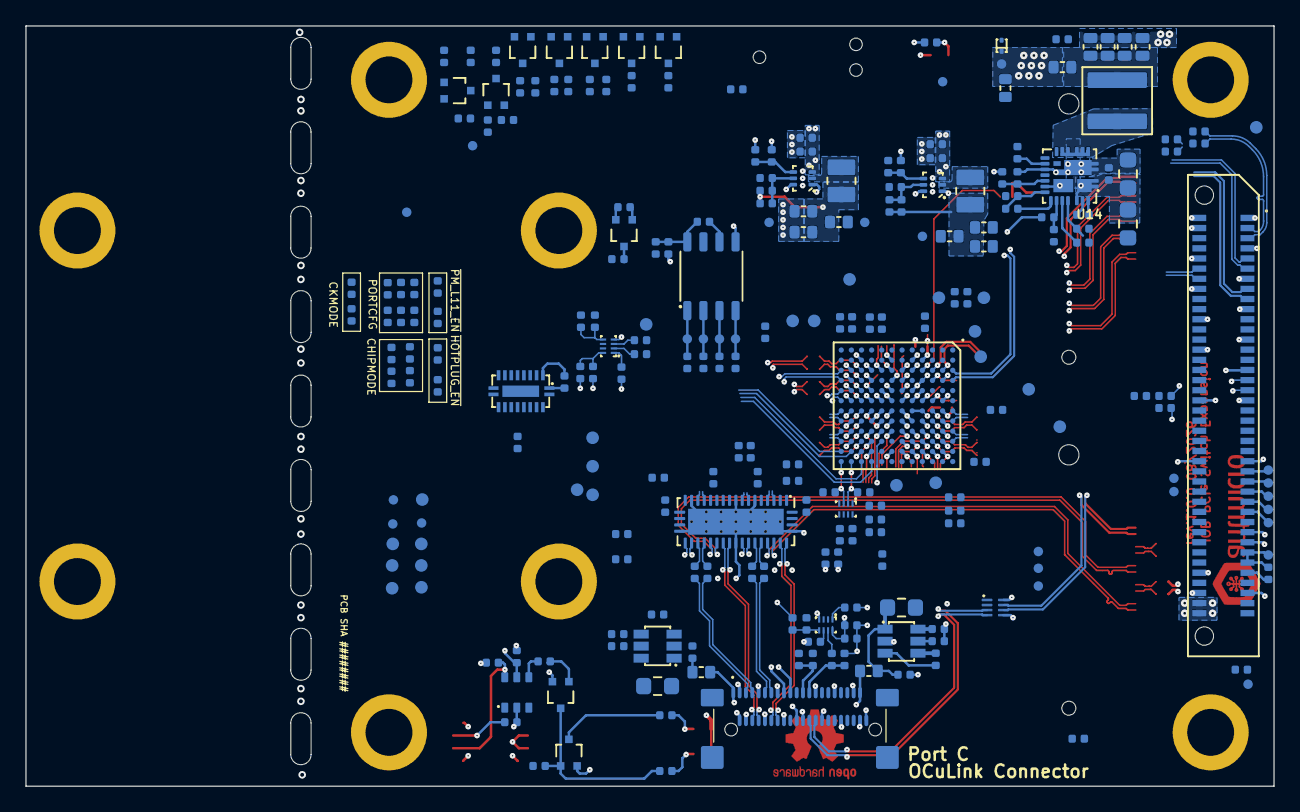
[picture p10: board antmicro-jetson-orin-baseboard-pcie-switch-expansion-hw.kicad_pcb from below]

Board: 6 copper layers, 98.5 x 60.0 mm, 341 parts (251 on the bottom side), 253 nets.

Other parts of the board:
C7, C9, C11: C_10u_0402; C_0402_1005Metric
C8, C10, C12: C_1u_0402; C_0402_1005Metric
D2: LED_G_0603_KP-1608CGCK; LED_0603_1608Metric_G
H10, H12: Spacer_Drill3.7mm_H2.5mm_9774025151R
J2: Bus_M.2_1-2199230-6; Bus_M.2_Socket_Key_M_TE_1-2199230-6
R7: R_0R_0402; R_0402_1005Metric
R8, R9, R10: R_10k_0402; R_0402_1005Metric
R11: R_470R_0402; R_0402_1005Metric
R12: R_0R_22.4A_0603; R_0603_1608Metric
TP5, TP6, TP7, TP8: TP_0.75mm_SMD; TP_SMD_0.75mm

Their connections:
+3V3: R8.2, R9.2, R10.2, R11.2, R12.2; also elsewhere on the board
/M.2 port B/PCIe_{x2}.CLK_N: J2.53 (REFCLK_N); also elsewhere on the board
/M.2 port B/PCIe_{x2}.CLK_P: J2.55 (REFCLK_P); also elsewhere on the board
/M.2 port B/PCIe_{x2}.RX0_N: J2.41 (PER0_N); also elsewhere on the board
/M.2 port B/PCIe_{x2}.RX0_P: J2.43 (PER0_P); also elsewhere on the board
/M.2 port B/PCIe_{x2}.RX1_N: J2.29 (PER1_N); also elsewhere on the board
/M.2 port B/PCIe_{x2}.RX1_P: J2.31 (PER1_P); also elsewhere on the board
/M.2 port B/PCIe_{x2}.TX0_N: J2.47 (PET0_N); also elsewhere on the board
/M.2 port B/PCIe_{x2}.TX0_P: J2.49 (PET0_P); also elsewhere on the board
/M.2 port B/PCIe_{x2}.TX1_N: J2.35 (PET1_N); also elsewhere on the board
/M.2 port B/PCIe_{x2}.TX1_P: J2.37 (PET1_P); also elsewhere on the board
/M.2 port B/PCIe_{x2}.~CLK_REQ: J2.52 (~CLKREQ), R9.1; also elsewhere on the board
/M.2 port B/PCIe_{x2}.~RST: R7.2; also elsewhere on the board
GND: C7.1, C8.1, C9.1, C10.1, C11.1, C12.1, H10.1, H12.1, J2.1 (GND), J2.3 (GND), J2.9 (GND), J2.15 (GND), J2.21 (GND), J2.27 (GND), J2.33 (GND), J2.39 (GND), J2.45 (GND), J2.51 (GND), J2.57 (GND), J2.71 (GND), J2.73 (GND), J2.75 (GND), J2.MP1 (MP), J2.MP2 (MP); also elsewhere on the board
unnamed: C7.2, C8.2, C9.2, C10.2, C11.2, C12.2, J2.2 (3V3), J2.4 (3V3), J2.12 (3V3), J2.14 (3V3), J2.16 (3V3), J2.18 (3V3), J2.70 (3V3), J2.72 (3V3), J2.74 (3V3), R12.1
unnamed: D2.2 (A), R11.1
unnamed: D2.1 (C), J2.10 (LED)
unnamed: J2.44 (ALERT), TP6.1 (1_1)
unnamed: J2.40 (SMB_CLK), TP8.1 (1_1)
unnamed: J2.42 (SMB_DATA), TP7.1 (1_1)
unnamed: J2.68 (SUSCLK), TP5.1 (1_1)
unnamed: J2.50 (~PERST), R7.1, R8.1
unnamed: J2.54 (~PEWAKE), R10.1

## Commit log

2026-07-10 Saved with KiCad 10
    [antmicro-jetson-orin-baseboard-pcie-switch-expansion-hw.kicad_pcb]
2026-07-10 [#100645] Update stackup & prepare mock
    [antmicro-jetson-orin-baseboard-pcie-switch-expansion-hw.kicad_pcb, antmicro-jetson-orin-baseboard-pcie-switch-expansion-hw.kicad_sch]
2026-07-13 [#100645] Add Antmicro and OSH logo
    [antmicro-jetson-orin-baseboard-pcie-switch-expansion-hw.kicad_pcb]
2026-07-14 [#100765] Add subsheets, import bus alias definitions
    [antmicro-jetson-orin-baseboard-pcie-switch-expansion-hw.kicad_sch, expansion-conn.kicad_sch, m-2.kicad_sch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]
2026-07-14 [#100765] Update Top Level schematic
    [antmicro-jetson-orin-baseboard-pcie-switch-expansion-hw.kicad_sch]
2026-07-14 [#100765] Update M.2 subsheet
    [m-2.kicad_sch]
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2026-07-14 [#100765] Add lane config tables
    [expansion-conn.kicad_sch]
2026-07-14 [#100765] Update symbol and tables
    [pcie-switch.kicad_sch]
2026-07-14 [#100765] Update top level schematic, add comments
    [antmicro-jetson-orin-baseboard-pcie-switch-expansion-hw.kicad_sch, oculink.kicad_sch]
2026-07-15 [#100765] Add PCIe connecions to M.2 slot A
    [pcie-switch.kicad_sch]
2026-07-15 [#100765] Add JTAG for PCIe switch, add power pins
    [pcie-mux.kicad_sch]
2026-07-15 [#100765] Update PCIe switch
    [pcie-switch.kicad_sch]
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2026-07-16 [#100765] Update M.2 3V3 line
    [m-2.kicad_sch, pcie-switch.kicad_sch]
2026-07-16 [#100765] Remove I2C from OCuLink
    [oculink.kicad_sch]
2026-07-16 [#100765] Add LLC to I2C of the PCIe switch
    [expansion-conn.kicad_sch, pcie-switch.kicad_sch]
2026-07-16 [#100765] Add Control LEDs, update Power section
    [pcie-switch.kicad_sch, supply.kicad_sch]
2026-07-16 [#100765] Work on schematic
    [antmicro-jetson-orin-baseboard-pcie-switch-expansion-hw.kicad_sch, eeprom_tagconnect.kicad_sch, oculink.kicad_sch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]
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2026-07-20 [#100765] Change sheet format to A3, update schematic
    [antmicro-jetson-orin-baseboard-pcie-switch-expansion-hw.kicad_sch, expansion-conn.kicad_sch, m-2.kicad_sch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]
2026-07-20 [#100765] Move caps near EEPROM
    [eeprom_tagconnect.kicad_sch]
2026-07-22 [#100765] Prettify decoupling caps
    [eeprom_tagconnect.kicad_sch, oculink.kicad_sch, pcie-switch.kicad_sch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]
2026-07-23 [#100765] WIP: Apply review changes
    [antmicro-jetson-orin-baseboard-pcie-switch-expansion-hw.kicad_sch, eeprom_tagconnect.kicad_sch, expansion-conn.kicad_sch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]
2026-07-23 [#100765] Change tag connect to DNP
    [eeprom_tagconnect.kicad_sch]
2026-07-23 [#100765] Change MAX3373EEKA+ to NTS0302JKZ
    [oculink.kicad_sch, pcie-mux.kicad_sch, pcie-switch.kicad_sch]
2026-07-23 [#100765] Apply fixes from review
    [antmicro-jetson-orin-baseboard-pcie-switch-expansion-hw.kicad_pcb, antmicro-jetson-orin-baseboard-pcie-switch-expansion-hw.kicad_sch, eeprom_tagconnect.kicad_s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]
2026-07-23 [#100765] Update top sheet
    [antmicro-jetson-orin-baseboard-pcie-switch-expansion-hw.kicad_sch]
2026-07-23 [#100765] Reset designators
    [antmicro-jetson-orin-baseboard-pcie-switch-expansion-hw.kicad_sch, expansion-conn.kicad_sch, m-2.kicad_sch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]
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2026-07-23 [#100765] Fix legacy DNP & Remove obsolete spacer drills
    [antmicro-jetson-orin-baseboard-pcie-switch-expansion-hw.kicad_pcb, antmicro-jetson-orin-baseboard-pcie-switch-expansion-hw.kicad_sch, m-2.kicad_sch]
2026-07-23 [#101557] Add spacers from 2242 M.2 disks
    [m-2.kicad_sch]
2026-07-23 [#101557] Place m.2, expansion connector and spacers
    [antmicro-jetson-orin-baseboard-pcie-switch-expansion-hw.kicad_pcb]
2026-07-24 [#101557] Fix designator in status LED label
    [pcie-mux.kicad_sch]
2026-07-24 [#101557] Remove obsolete 0R on CWAKE# and CPRSNT#
    [oculink.kicad_sch]
2026-07-24 [#101557] Add 0R on EEPROM VCC
    [pcie-switch.kicad_sch]
2026-07-24 [#101557] Replace 0402 0R to 0R_22.4A
    [oculink.kicad_sch]
2026-07-24 [#101557] Add decoupling caps on VDDR, C_VDDR and VPH
    [antmicro-jetson-orin-baseboard-pcie-switch-expansion-hw.kicad_pcb, pcie-switch.kicad_sch]
2026-07-24 [#101557] WIP: Component placement
    [antmicro-jetson-orin-baseboard-pcie-switch-expansion-hw.kicad_pcb]
2026-07-27 [#101557] Finish component placement
    [antmicro-jetson-orin-baseboard-pcie-switch-expansion-hw.kicad_pcb]
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2026-07-27 [#101557] Move power section
    [antmicro-jetson-orin-baseboard-pcie-switch-expansion-hw.kicad_pcb]
2026-07-27 [#101557] Define netclasses & custom rules
    [antmicro-jetson-orin-baseboard-pcie-switch-expansion-hw.kicad_pcb]
2026-07-27 [#101557] Change status led to HP_LED4
    [pcie-switch.kicad_sch]
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2026-07-28 [#101557] Add additional labels on HS lines
    [pcie-mux.kicad_sch, pcie-switch.kicad_sch]
2026-07-28 [#101859] Change 2242 M.2 drilled mounts to DNP
    [antmicro-jetson-orin-baseboard-pcie-switch-expansion-hw.kicad_pcb, m-2.kicad_sch]
2026-07-28 [#101859] Prettify silkscreen, mark boostrap signals
    [antmicro-jetson-orin-baseboard-pcie-switch-expansion-hw.kicad_pcb, pcie-switch.kicad_sch]
2026-07-28 [#101859] WIP: Add BGA fanout
    [antmicro-jetson-orin-baseboard-pcie-switch-expansion-hw.kicad_pcb]
2026-07-29 [#101859] Add HS fanout from connectors
    [antmicro-jetson-orin-baseboard-pcie-switch-expansion-hw.kicad_pcb, pcie-mux.kicad_sch, pcie-switch.kicad_sch]
2026-07-29 [#101557] Group bootstraps, route VCC section
    [antmicro-jetson-orin-baseboard-pcie-switch-expansion-hw.kicad_pcb]
2026-07-29 [#101557] Route power section
    [antmicro-jetson-orin-baseboard-pcie-switch-expansion-hw.kicad_pcb]
2026-07-29 [#101557] Add intentional PCIe polarity swap on U10
    [antmicro-jetson-orin-baseboard-pcie-switch-expansion-hw.kicad_pcb, pcie-mux.kicad_sch]
2026-07-29 [#101557] WIP: routing PCIe mux
    [antmicro-jetson-orin-baseboard-pcie-switch-expansion-hw.kicad_pcb]
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2026-07-30 [#102081] Start BGA Fanout
    [antmicro-jetson-orin-baseboard-pcie-switch-expansion-hw.kicad_pcb]
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

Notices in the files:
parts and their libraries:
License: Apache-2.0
